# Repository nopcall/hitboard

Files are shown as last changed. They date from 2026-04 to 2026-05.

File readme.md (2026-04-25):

### HITBOARD 开源项目

Hitboard 是一个开源 Hitbox 项目，包含 Zero、Air 等不用型号以适应不同用户、不同场景的需求。它诞生于一个简单的需求：为何不能有一台既拥有键盘的紧凑布局，又具备 Hitbox 专业输入体验的设备？

本项目不仅提供可生产的文件，更完整记录了从 设计思路、CAD布局、PCB工业化 到 固件配置 的全流程。你可以直接使用，也可以将其作为起点，打造属于你自己的终极武器。

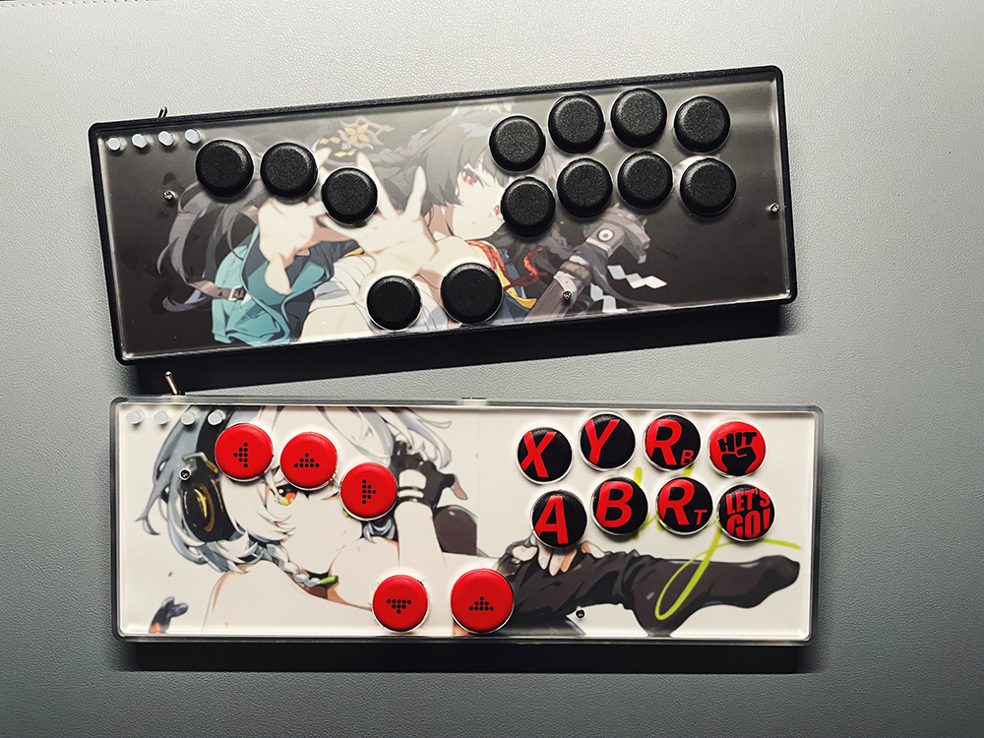
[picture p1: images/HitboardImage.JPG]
Hitboard成品图


#### 🎬 项目视频实录

本项目的完整诞生过程，已通过系列视频详细记录。如果你对背后的思考、踩坑的经历和具体的制作步骤感兴趣，强烈建议观看：

【【街霸6】180元手搓 Hitbox | 附材料清单设计源文件】 https://www.bilibili.com/video/BV1n8UQBeEs3/?share_source=copy_web&vd_source=521fa607e5f082de7ab25fcafb9cb9a2

【手搓Hitbox 第二弹：全程组装实录】 https://www.bilibili.com/video/BV15iUfBCE8V/?share_source=copy_web&vd_source=521fa607e5f082de7ab25fcafb9cb9a2

【手搓Hitbox 第三弹：生成CAD文件】 https://www.bilibili.com/video/BV1XumPBUEJE/?share_source=copy_web&vd_source=521fa607e5f082de7ab25fcafb9cb9a2

#### ✨ 型号说明
Hitboard Zero

从零开始的起点，为渴望亲手定义操控的创造者而生。纯亚克力多层结构，只需简单修改CAD文件即可调整布局，一切由你决定。这里仅提一套参考布局、PCB 源文件作为灵感，而非定死的答案。288×96mm键盘尺寸无缝融入桌面，双面壁纸让美学随你变换。它是你打造专属控制器的空白画布，也是通往深度定制的第一级台阶。

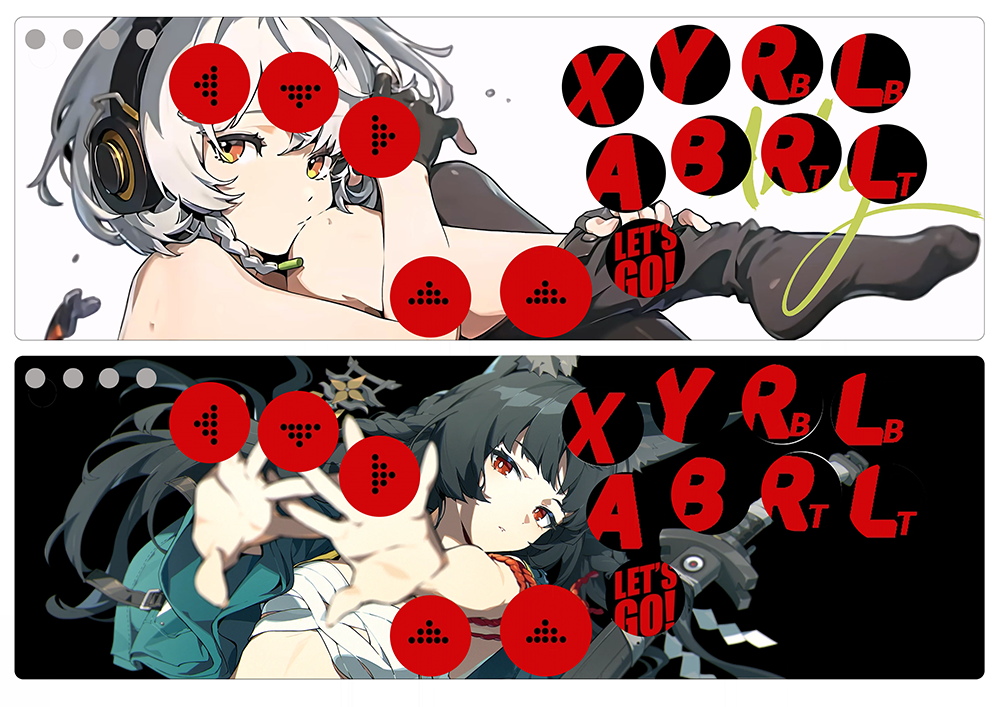
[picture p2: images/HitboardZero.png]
Hitboard Zero


Hitboard Air

像拼四驱车一样拼 Hitbox。基于3D打印技术实现，256mm宽度适配家用打印机。保留Zero的全尺寸按键布局，并提供更灵动的“拨片”加键。所有电路部分均为卡扣结构，可以方便的拆卸转移。

//由于卡扣结构的设计极其复杂，牵一发动全身。此型号提供全套 3D 打印文件作为标准答案。

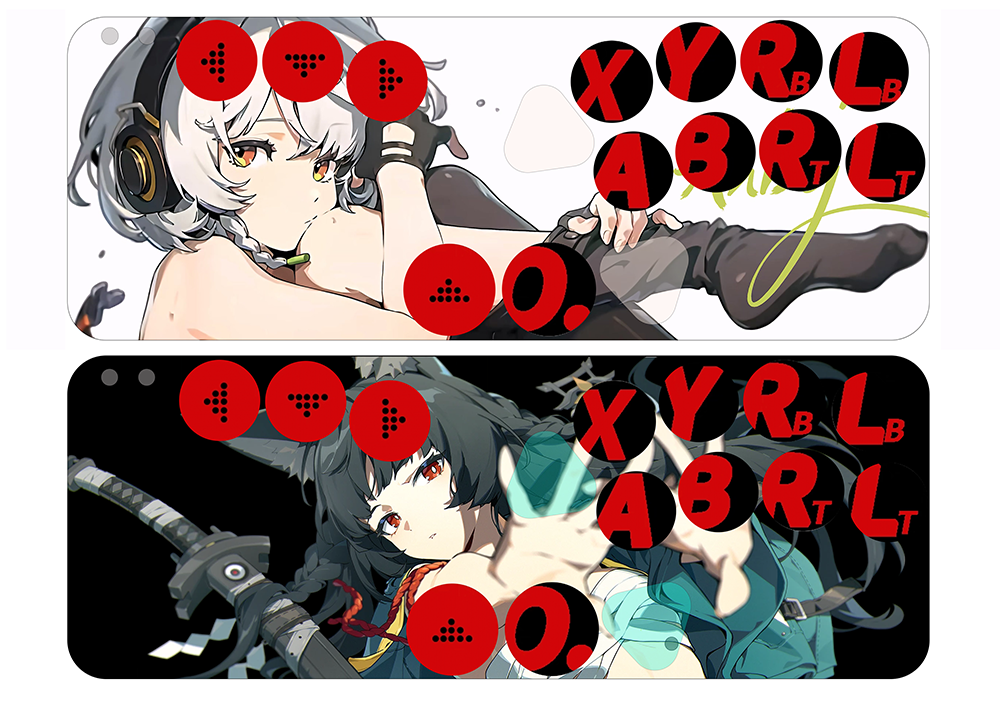
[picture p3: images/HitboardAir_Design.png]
Hitboard Air


Hitboard Classic

Hitboard Classic – 不只是摇杆：可翻转、可滑动、可换轴、可配重、可塞主板的开源格斗外设平台。

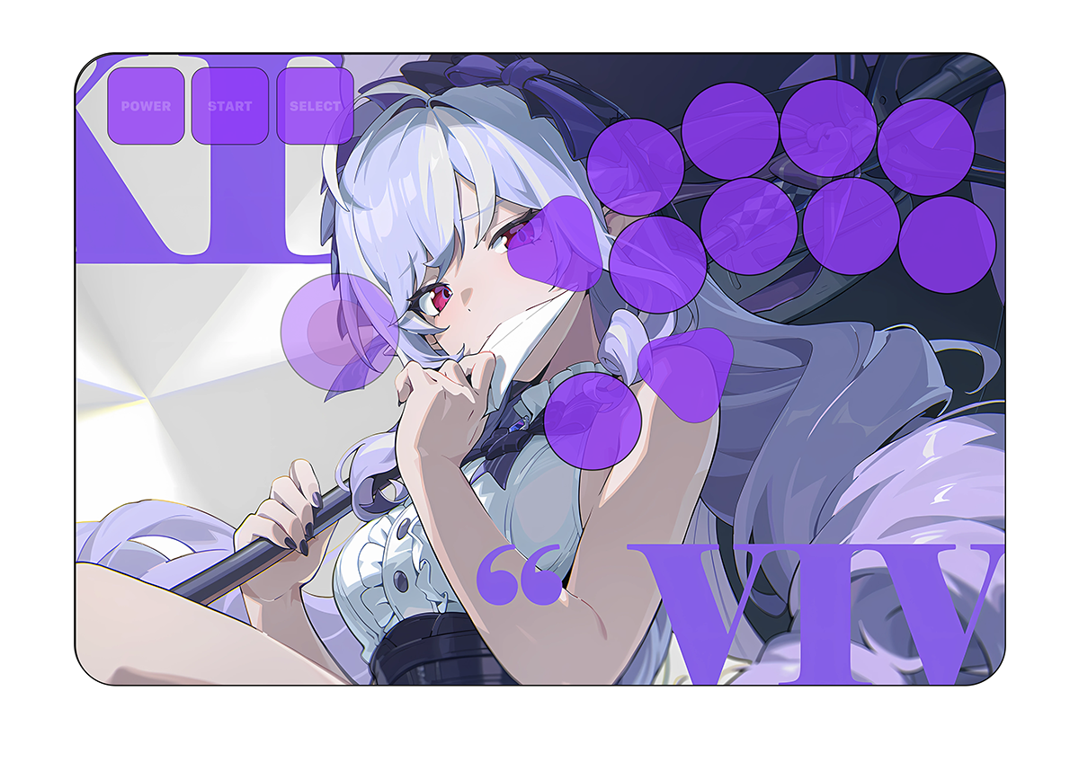
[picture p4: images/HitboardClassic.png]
Hitboard Classic


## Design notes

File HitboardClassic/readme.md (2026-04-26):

Hitboard Classic

Hitboard Classic – 不只是摇杆：可翻转、可滑动、可换轴、可配重、可塞主板的开源格斗外设平台。

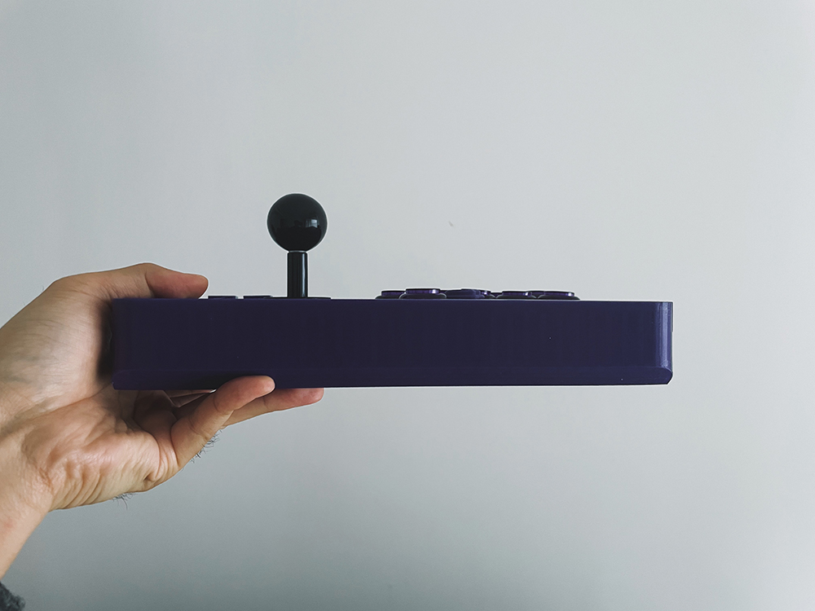
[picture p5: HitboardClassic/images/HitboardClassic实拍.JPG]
Hitboard Classic


Hitboard Classic —— 不只是摇杆

开场：科学街霸标准。
过去一段时间，我们一直在探索一个问题——好的格斗游戏外设，应该是什么样的。

由此提炼出一套科学街霸外设的标准：
* 分离式布局，放松肩膀。
* 左右对称 + 合理按键布局，减少手指疲劳。
* 功能键触手可及，提高训练场效率。
* 拨片加键键帽，跟拳脚键区分度高，不误触。
* 23-26mm 黄金尺寸，平衡触感与按键间距。
* 面板使用非金属、非玻璃材质，防止手感冰凉。

依据这些标准，我们做了 Hitboard Air。
但格斗外设，从来不该只有 Hitbox 这一种答案。

#### Hitboard vs 街机摇杆
Hitbox 把方向拆成四个独立开关——大脑先解构，手指再敲击。一步错，步步错。

街机摇杆不同。手掌、手腕、小臂协同发力——转圈、半圆，手腕一抖就出来。
长盘更稳，压力分散。这就是摇杆的哲学：不是更快，是更稳；不是拆解，是本能。

那既然摇杆这么科学，为什么被 Hitbox 抢尽风头，甚至举步维艰？
不是它不行了，是缺少创新的外设厂商，让摇杆跟不上时代。

通过本期视频——我们来让摇杆，再次伟大。

####第一部分：传统摇杆的问题

布局问题：
33mm 按键间距，手指根本够不顺。
功能键又小又远，训练场里形同虚设。
左右手高低差——视觉上对齐了，用起来却一高一低。
结果：手掌频繁抬起、移动，多出废操作。手被架空。
需要给设备增加配重来减少晃动。

摇杆问题：
圆档丝滑但蹲防不准，方档准但搓招卡。
八角档两边不讨好。厂商图省事，丢给你一个“能用就行”。

按键问题：
街机按键手感特殊，键盘玩家上来就劝退。
想换自己喜欢的 MX 轴或矮轴？没门——轴座又贵又难改。

外观问题：
又大又重，2公斤起步，放桌上占半张桌，放腿上压得慌。
想自己动手改？纯亚克力堆叠，山寨感拉满。

这样，新人还没入门，就被劝退。

####第二部分：Hitboard Classic 带来的新基准

基于此场景，我们推出 Hitboard Classic，用全新的基准来解决以上所有问题。

基准 1：科学布局
分离式布局
摇杆和按键拉开距离，肩膀自然放松。

对称布局
手掌对称，不是按键对称。
传统摇杆左右手高低差约35mm，Classic 把这个落差做到结构里，左右手掌始终在同一水平线。

优化的拳脚键布局
手掌自然放置就能覆盖所有按键。
现代模式也顺手。
自然放置的手掌，给设备提供了下压力，搓招不晃动。

功能键触手可及
功能键同 Air 一样放在左上角位置，左手无名指一勾就能按到，手不离杆。
三颗功能键，菜单、Func、重置，一个不落，提升训练场效率。

#### 基准 2：黄金摇杆标准

衡量摇杆好不好用，看两个指令：半圆、前前。

传统摇杆的问题：
圆档滑，但斜角没档位，蹲防拉不到位。
玩家被迫换方圆档/八角档。蹲防稳了，但因为相比圆档压缩了活动空间，摇杆被吃掉了行程。

行程变短带来两个问题：搓招指令不清晰；弹簧弹力变小，回中变慢，影响前前指令。
为了补漏洞，就得换大弹力弹簧，整个手感反人类——就像骑最高齿比的自行车上坡，腿脚根本不受控。

Classic 的方案：圆方档位。
优先保证圆的丝滑，四角做小切角。
不刻意拉斜方向时，它就是圆；拉斜方向时，蹲防清晰。

使用圆方档位，能让前后指令吃满行程。
这样，玩家可以用轻克力弹簧，通过行程带来的张力来回中。
相比通过大力弹簧硬拉，更符合直觉。
行程大，更不容易串招。

人类的手掌非常敏锐，虽然只差了几个毫米的行程，几个克的弹力曲线。
但，理顺了，自然了，就好上手。
新手几乎零学习成本，练一练就能追上自己 Hitbox 的操作水平。

#### 基准 3：快装轴座系统，实现按键自由

轴座自由
想用街机按键？可以。
想用 MX 轴？可以。
想用矮轴？也可以。

Classic 的快装轴座系统：买几个插簧，简单一装，就是机械轴轴座。
提供 MX 轴 / 矮轴 两种型号。
配合 24mm 盖板开孔，街机按键、矮轴、MX 轴，随便换。

根据每种轴体的行程，做了按键深度的适配，每种按键的按压都恰到好处。

键帽自由
提供 21mm 键帽（硬朗/圆润两种弧度），通过深度与边缘的配合，手感接近 23mm 键帽。
你也可以选择第三方的 21mm 键帽。
加键依然提供拨片形，薄、与拳脚键区分度高，不误触。
功能键支持全尺寸的键盘键帽。

### 基准 4：从极致的薄，到舒适的厚

Air 做到了 9.3mm，全球最薄。因为它定位在桌面环境，越薄体验越好。

Classic 更多的考虑了舒适度、健康度问题？
如何能远离屏幕，如何能更放松。
答案是，放在腿上使用。

为了放腿上，就需要一定的厚度，给手臂支撑，减轻手腕压力，
为了广泛兼容玩家喜欢的各类摇杆，就需要 36mm 以上的内部空间。
为了实现壁纸自由，需要再留出 4mm 的亚克力盖板厚度，
那么，40mm 就是满足舒适性、可玩性、摇杆类产品的，最薄极限。

这个厚度，在视觉上恰好不会显得厚重。
配合长宽比、一定的切角设计，使它看起来很小巧，愿意把玩。

与市面上的摇杆相比：
传统摇杆：35×21×5.5 cm，4042 cm³，2kg。
Hitboard Classic：25.6×17.4×4 cm，1781 cm³，650g。
体积少 56%，重量轻 60%。

得益于基准 1，在全面减负的情况下。
你得到了对手臂友好的、不压腿的、布局开阔无晃动的，街机摇杆。

广阔的内部空间，也带来了更多的电路选项。
可以继续使用Pico + GP2040，获得易用的手柄/键盘系统。
也可以加入电池、无线芯片，来 DIY 无线方案。
甚至可以50 块买个二手手柄，拆主板、电池，放进去秒变无线摇杆。

#### 总结：

Hitboard Classic 新基准

人体工学布局 —— 手掌对称，功能键触手可及

黄金摇杆标准 —— 圆方档位，丝滑且精准

快装轴座系统 —— 按键自由，免焊接零门槛

从极致的薄，到舒适的厚 —— 放腿无压，久玩不累

一套新基准，使摇杆变得科学、趁手、自由。
让摇杆，再次，伟大。

#### One more thing……一切皆可自定义

左右自定义
左撇子？右手方向、左手拳脚？
Classic 外壳左右对称，盖板上下对称。
翻转一下，镜像布局。
从形态到习惯，全部自定义。

形态自定义
不知道自己适合摇杆、Hitbox 还是 Mixbox？
Classic 全模块化设计。
拆掉摇杆，装上四个方向键 = Hitbox。
换上 WASD 盖板 = Mixbox。

配件自定义：
内部多个轨道，提供束线器、磁吸模块、电池仓、马达仓。按需 DIY。

Hitboard Classic 是什么？
不只是街机摇杆，而是一个格斗外设 DIY 平台。

如何开始？
Hitboard Creator for Classic，硬件自由，软件也自由。
一如既往简单强大。
一如既往，GitHub 搜索 Hitboard，打开网页工具，马上开始设计。

Hitboard
Find your fight.

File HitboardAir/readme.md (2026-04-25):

### Hitboard Air - 组装指南

### 准备工作：采购元器件

1. 下载网页工具：00_设计你的 Hitboard Air.html

2. 用浏览器打开该网页，设计你的 Hitboard。设计完成后，点击页面中的「导出产品配置」按钮，导出你的配置图片。

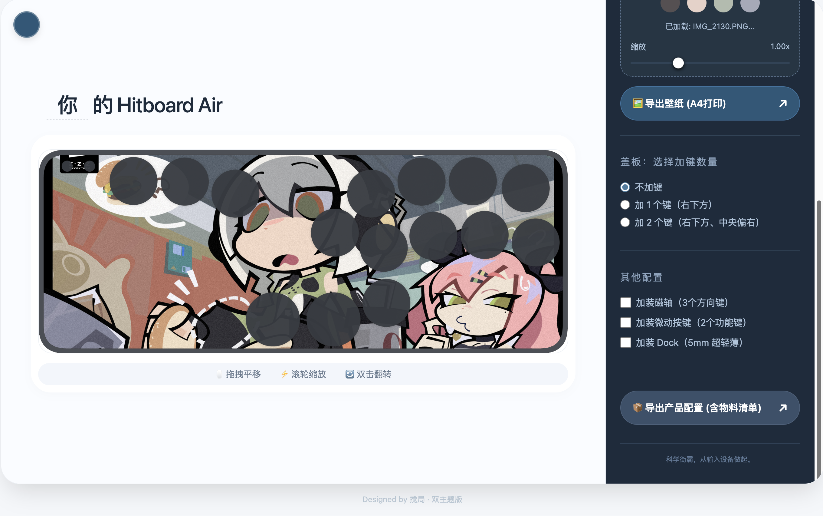
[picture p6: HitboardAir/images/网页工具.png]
HitboardAir 全部打印件


3. 根据配置图片中的物料清单，采购元器件、3D 打印套件。

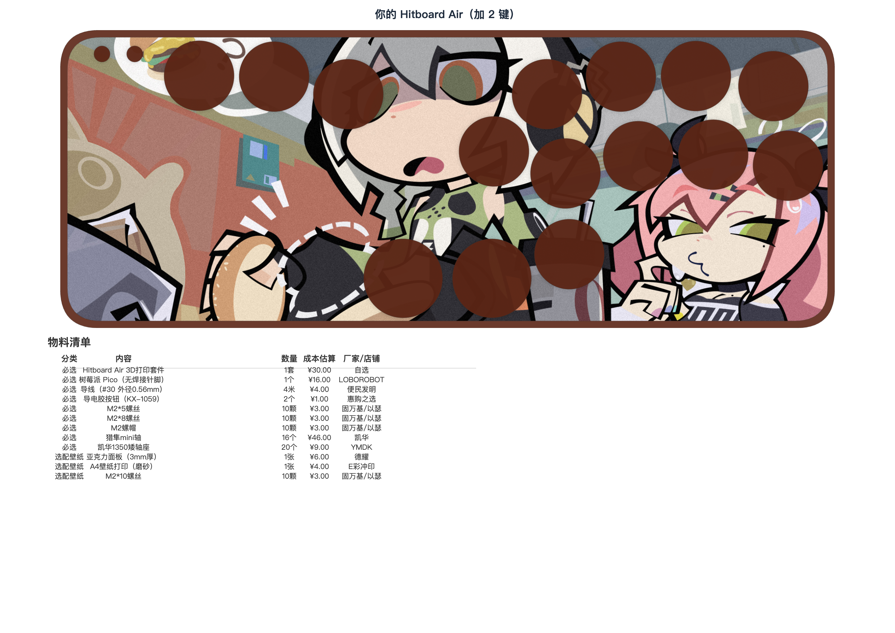
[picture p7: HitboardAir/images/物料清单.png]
HitboardAir 全部打印件


**3D 打印文件怎么选**

02_3D_Files 目录，包含两套 3D 打印文件，分别是：

「Hitboard Air - 圆润版」

「Hitboard Air - 硬朗版」

//两个版本只有外壳、按键的弧度有区别，内部零件通用。根据你喜欢的风格二选一，或全都选，即可。

HitboardAir 全部打印件

### 组装过程

### 第一步：给 Pico 刷入 GP2040 固件

1. 按住 Pico 复位按钮的同时，通过 typec 数据线连接 Pico 到电脑。此时 Pico 将会以 U 盘的形式出现。
    
2. 将固件「GP2040-CE_0.7.12_Pico.uf2」文件，拖拽到 Pico U 盘。
    
3. 等待几秒钟，Pico 会被重新识别为手柄。可以在手柄测试网页 https://hardwaretester.com/gamepad 查看手柄状态，用导线短接 GND 和任意信号引脚查看是否工作。

### 第二步：飞线连接元器件

打开「Pico背面图片」，观察的引脚示意图，了解引脚的基本情况。

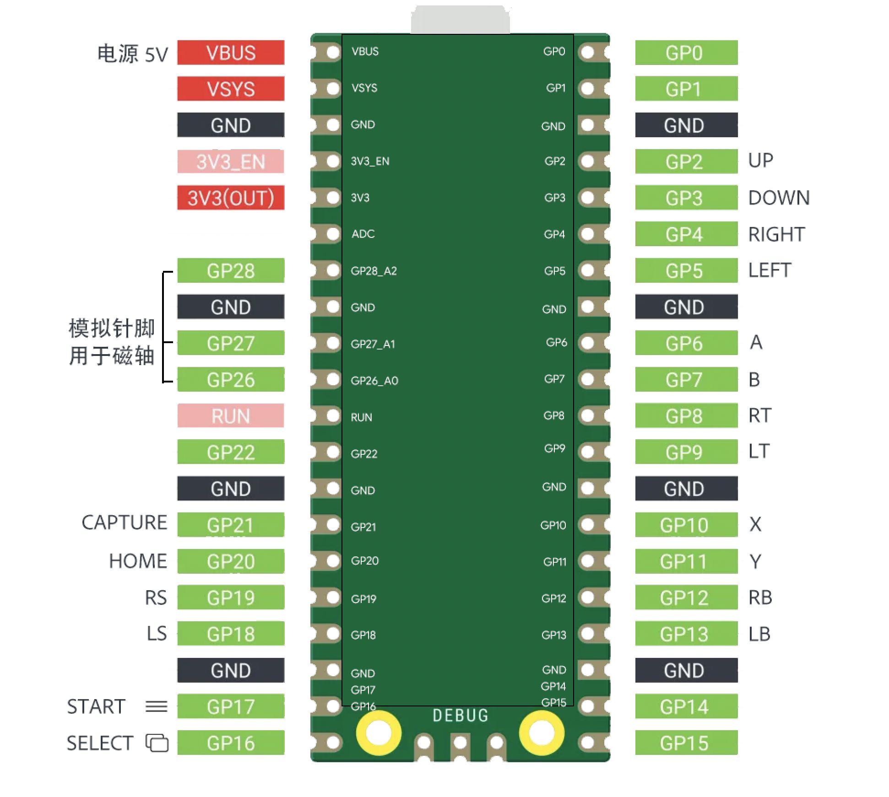
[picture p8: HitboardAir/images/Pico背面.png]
HitboardAir 全部打印件


1. 拿出「Hitboard Air 03 线路板」，板子上布满卡扣，依次将 Pico、轴座卡在对应的位置。

**注意！一定要是正面（有 USB 凸起）朝里，背面（绿色纯平面）朝向自己卡进去。**

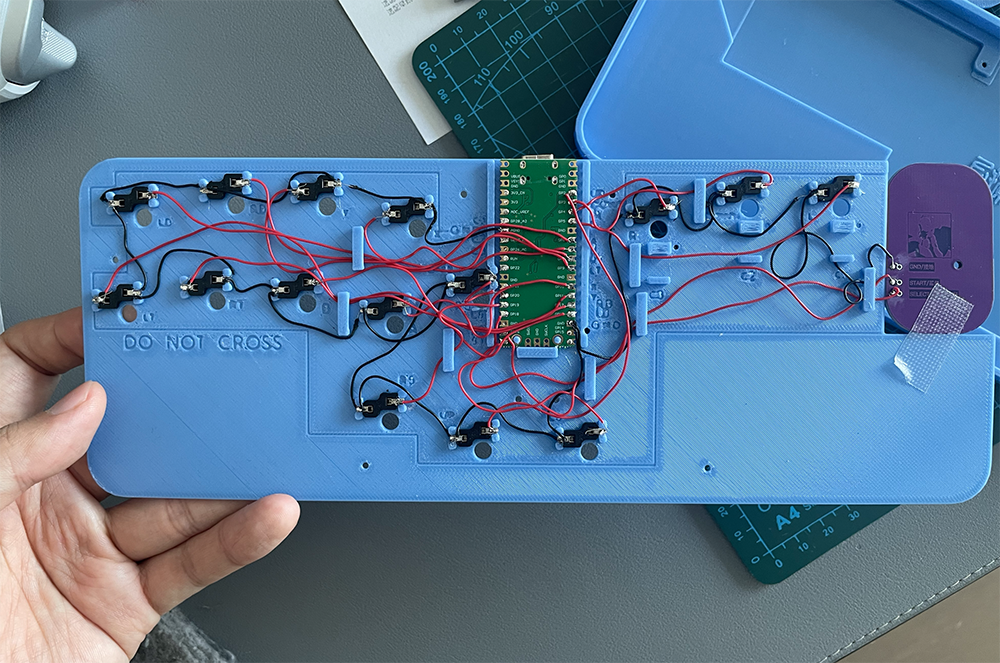
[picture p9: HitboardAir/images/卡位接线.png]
HitboardAir 全部打印件

    
2. 连接
    
    首先，留意线路板上的“警戒线”标注，警戒线内对应底壳空腔，表示线路可以被容纳。如果超出警戒线，则线路无法被容纳，组装时，无法放平整。

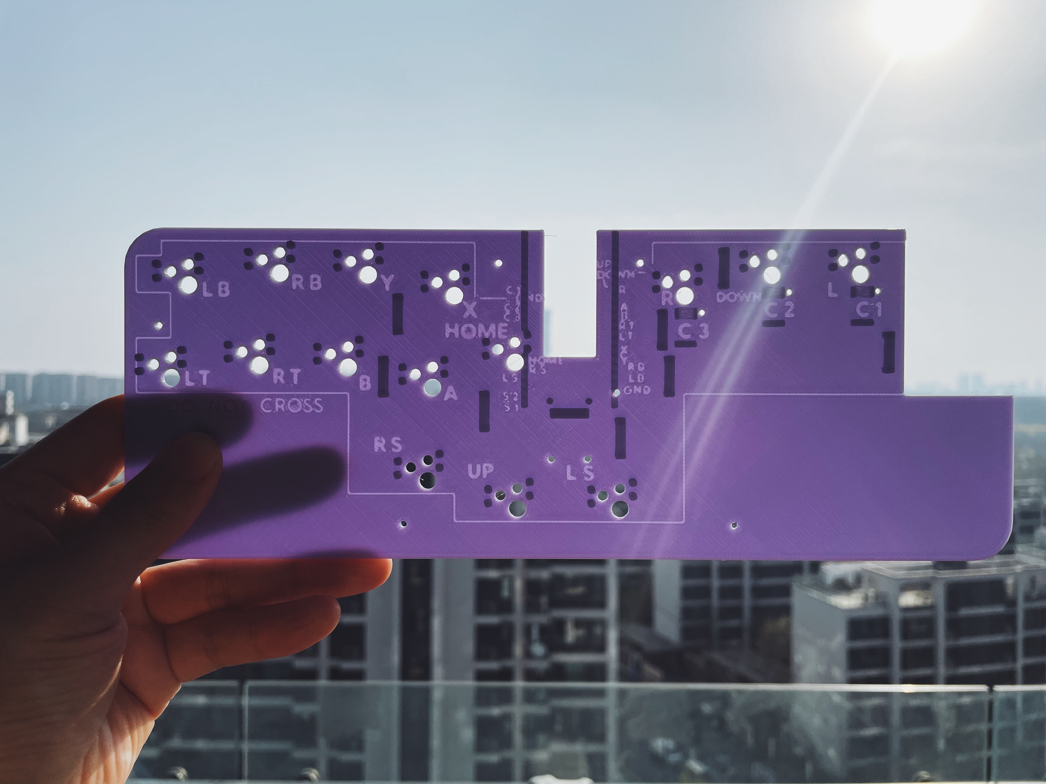
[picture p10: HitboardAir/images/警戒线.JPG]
HitboardAir 全部打印件


先来给每个按键接 GND。
    
    从 Pico 的任意 GND 方形焊盘，引出导线，将导线依次通过每一个轴座的任一引脚，焊接确保联通（或者缠绕连接）。这样就完成了按键的接地。
        
    将按键轴座另外一个引脚，接到对应的功能。比如方向键「Up」连接到 GP2 Up。
        
    把 4 个方向键、8 个功能键的轴座触点，通过导线，连到 Pico 对应的引脚。
        
    三个加键的轴座触点，连到 Pico 的 LS、RS、Home 引脚，后续需要在设置中，改为你需要的其他按键。

    Select、Start，默认使用导电胶+小电路板实现。把电路板上对应名字的焊盘，与 Pico 引脚相连即可。记得给小电路板连 GND。
        
    // 连接完成后，务必把 Pico 连接到电脑，用导线短接每个轴座的两个引脚。在手柄测试网页查看是否都能生效。
        
    // 如果不生效，检查是否虚焊，直到所有按键电路都正常工作。

### 第三步：组装所有板子

    将 03线路板、02定位板，依次放入04外壳。
    
    将轴体压入 02 定位板。//可以用手指挤压轴体左侧的外壳，让轴体不损耗卡扣
    
    放置导电胶按钮。
    
    准备盖板。通过 04 外壳的卡扣卡好即可。
    
    // 如果想要更牢固的固定盖板：
    
        先将 M2 螺丝帽，放入盖板背面的隐藏式螺帽仓。
    
        盖好盖板到外壳。
    
        从外壳背面，拧 6 颗 8mm M2 螺丝。
    
    从00按键中，取下按键，对应按键位置，一一装入。

### 软件设置

#### 按键配置

1. 按住 Start 按键的同时，通过 typec 连接电脑。
    
2. 访问 GP2040 Web 配置界面（通过 USB 连接后访问 192.168.7.1）
    
3. 点击「功能配置-GPIO 引脚配置」，将 LS、RS、Home 等按键，改为需要的按键。
    
    如果忘了哪个按键对应哪个。点击网页中的「引脚查看器」按钮，在 Hitboard 上按下需要配置的按键，网页会显示引脚编号（如果第一次检测无效就关闭弹窗再次点击）。
        
    在按键列表中找到对应的引脚，编辑按键即可。
        
#### 手柄性能设置：//必做

1. 点击「设置-游戏手柄设置」。
    
2. 将 SOCD 清理模式，改为「后输入优先」。
    
3. 将去抖延迟，改为 0 毫秒。

### 选配组件

#### Dock

先把本体滑入Dock上半。（滑入前，将 2 颗 M2 螺帽装入上半螺帽仓）

再把Dock下半卡入本体。

将 5mm M2 螺丝，分别从 Dock 左右两侧的螺丝孔拧入，即可完成固定。

锁线器：
    
    将 12 颗小磁铁，6 颗一组，压入锁线器的磁铁仓。
    
    将 6 颗小磁铁，3 颗一组，压入 Dock 的磁铁仓。
    
    将锁线器快装到 typec 数据线，即可使用磁吸锁线功能。

#### 盖板和壁纸

通过网页工具，制作下载壁纸图片。以 A4 尺寸打印，获得纸质壁纸。

对壁纸裁剪、打孔，取下 3D 打印盖板，替换为壁纸、亚克力盖板即可。

// 亚克力生产的 CAD 文件：其他/CAD 文件/Hitboard Air 亚克力.dwg

#### 磁轴

星磁mini轴的弹簧比较硬，我们先对弹簧手感进行调优。

剥开轴体，取下弹簧。将弹簧剪掉1/3。剪下的弹簧不要丢掉，以后可以用在功能键上。磁轴结构非常简洁，圆形磁铁对准圆形磁铁孔，装回即可。

这样轴体的手感就非常丝滑软弹了。如果想要磁轴、机械轴共存，剪掉磁轴右上方的塑料卡针即可。

搞定机械部分之后，我们开始处理电路。拿出选配零件中的霍尔传感器。窄面朝上，卡入线路板专用位置。传感器从右边起，分别是信号引脚、GND、3V3电压输入。每个传感器一一对应连接。

然后进入最后的软件校准环节。进入网页配置界面，
先进入LED配置，把默认占用的28引脚修改为其他引脚，释放这个模拟引脚。

然后进入插件设置，确保其他设置没占用模拟引脚的情况下，进入霍尔设置。

设置直连，26、27、28。然后对每个引脚绑定手柄键值，然后校准。

这里可以设置一个比较短的触发行程，让方向键快于拳脚键。对搓招儿的时间窗口比较有利。

最后保存触发值，重启设备。你的 Hitboard 就拥有了最顶级的性能。

### 关于手工缠线（免电烙铁）

手工缠线比电烙铁还要简单。要点是小孔缠线的技巧。
掐掉导线20cm左右的绝缘皮，对折导线头。

穿入对应的引脚焊盘孔，旋转Pico或导线，你就获得了由四股导线固定的引脚线
比单根导线有更大的强度和更大的接触面积。

绑定所有导线后，像装机走线那样集中安排走线就行了。

轴座端，缠两圈线，压扁轴座铁皮，一路引脚就固定好了。

轴座新增2个小过孔，方便GND裸导线从背面走线。

之后就是重复操作，不再赘述。

### 总结

我们从一堆散件开始，亲手完成了固件烧录、线路连接、整机组装和软件配置。最终得到的，不只是一台Hitboard——更是从零到一，把想法变成实物的能力。

科学街霸，从输入设备做起。Hitboard，让创造回归简单。

**【完】**

项目贡献者名单：@搅局无敌 @JennyPeng @匈牙利山猫 @Rev01ution

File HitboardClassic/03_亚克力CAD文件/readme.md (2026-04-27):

Hitboard Classic 亚克力

#### 1. 开孔尺寸

亚克力
考虑到亚克力厂家的公差，新版亚克力的「文件开孔直径」为 24.2mm，实得开孔直径大约为 24.3+-1。

3D 打印
直径24.6mm 的 PETG 打印轴座，收缩率之后，直径约为 24.4mm。

这样二者就能紧密卡住。

#### 2. 盖板尺寸

同样，根据公差，亚克力文件中的盖板宽高、圆角弧度，也跟 3D 打印文件中的盖板尺寸不同。

直接用一样的尺寸，会由亚克力厂的公差x3D 打印收缩率，而装不进去。

请知。

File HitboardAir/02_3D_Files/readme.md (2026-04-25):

### Hitboard Air - 3D打印设置

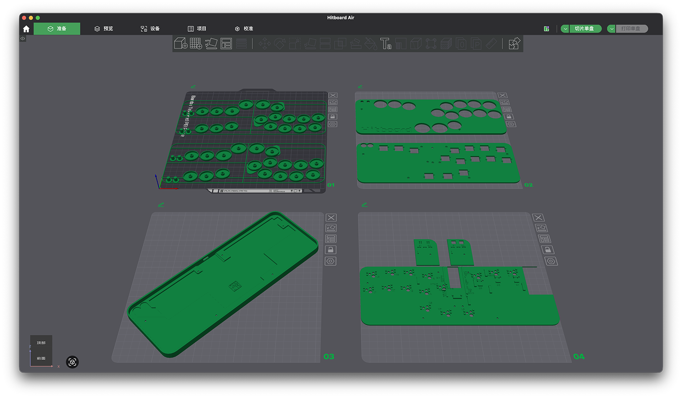
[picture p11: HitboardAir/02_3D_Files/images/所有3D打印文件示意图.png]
HitboardAir 全部打印件


#### 1. 文件说明

#### Hitboard Air 双版本 · 刚柔并济

**文件说明**

Hitboard Air 提供两种性格的版本——刚版与柔版。外壳、按键、Dock 三处的倒角设计，决定了设备整体的气质与手感。你可以根据自己的偏好，选择与你契合的那一款。

**刚 · 方正利落**
    
平整的极客体验。

    边缘干脆，线条直接。2.4mm 倒角仅做必要圆滑，保留直角带来的精准感。适合追求硬朗风格、喜欢清晰反馈的你。放在桌上，它是一块冷峻的金属感面板；握在手里，每一个棱角都在提醒你：这是一件趁手的工具。

**关键词：** 利落、精准、克制

**柔 · 圆润亲和**

温润的舒适体验。

    圆角过渡自然，握持更贴合手掌。每一个边缘都经过细致打磨，触感如鹅卵石般温润。适合长时间使用、偏爱柔和手感的你。它不会喧宾夺主，只是安静地承托你的每一次操作。

**关键词：** 圆润、舒适、包容

选择你的版本

刚与柔，没有好坏，只有不同。你的设备，该有你的性格。

##### 00_按键

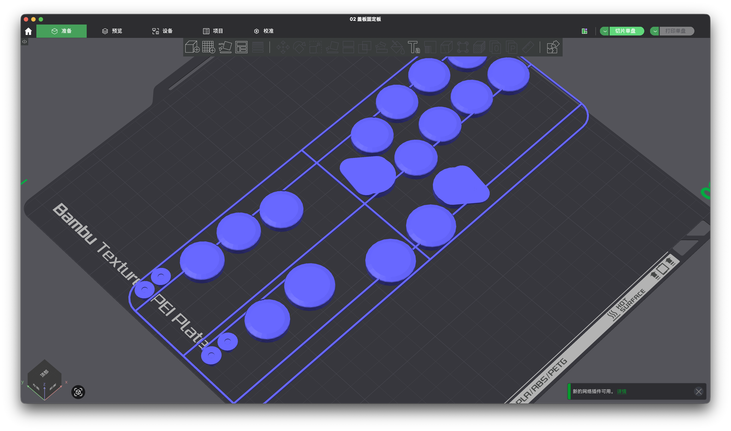
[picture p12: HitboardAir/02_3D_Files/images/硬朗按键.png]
HitboardAir 有刻键帽


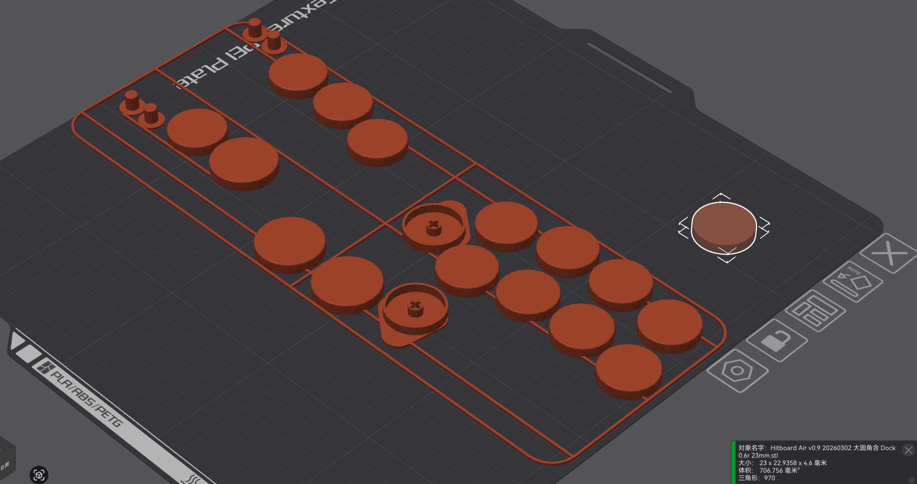
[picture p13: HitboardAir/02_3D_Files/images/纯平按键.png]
HitboardAir 有刻键帽


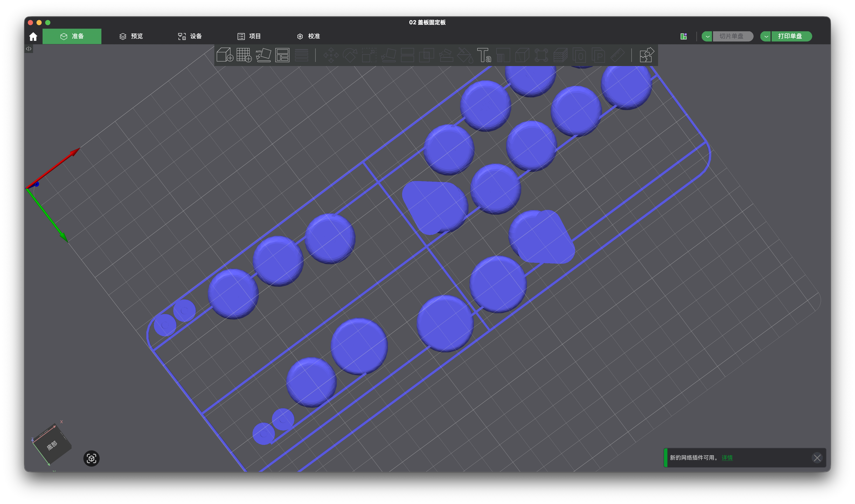
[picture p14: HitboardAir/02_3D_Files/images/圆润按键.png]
HitboardAir 有刻键帽


**键帽类型**

按键类型    命名    英文名    说明
2.5mm斜切    硬朗按键    Edge Key    线条硬朗，反馈清晰
0.6mm圆角    纯平按键    Flat Key    视觉纯平，手感顺滑不割手
3mm圆角    圆润按键    Round Key    明显圆角，手感柔和

**键帽触感**

按键根据键帽的朝向，有键帽朝上（正打）、键帽朝下（反打）两种方式。

正打能提供比较好的表面平整度，缺点是按键的确认感会不清晰。

反打按键的特点是，利用热床的颗粒，反打获得的表面随机颗粒效果，可以欺骗触觉（类似相机上的颗粒喷涂）。

// 注意：反打按键，需要在软件里把文件翻个朝向（也可以点击软件的「自动朝向」）。

**键帽刻字**

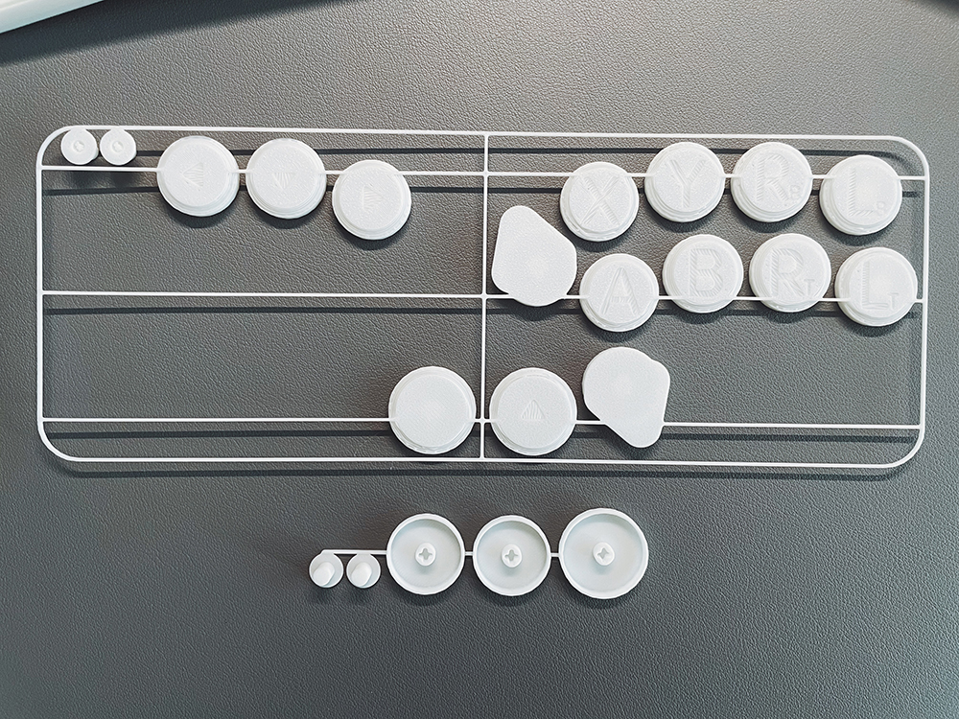
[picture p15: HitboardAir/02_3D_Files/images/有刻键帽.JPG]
HitboardAir 有刻键帽


有刻按键整体视觉上会好看一些，但会牺牲手感。推荐无刻。 （有刻在 More 文件夹中，有需要的自取）

##### ButtonsSystem

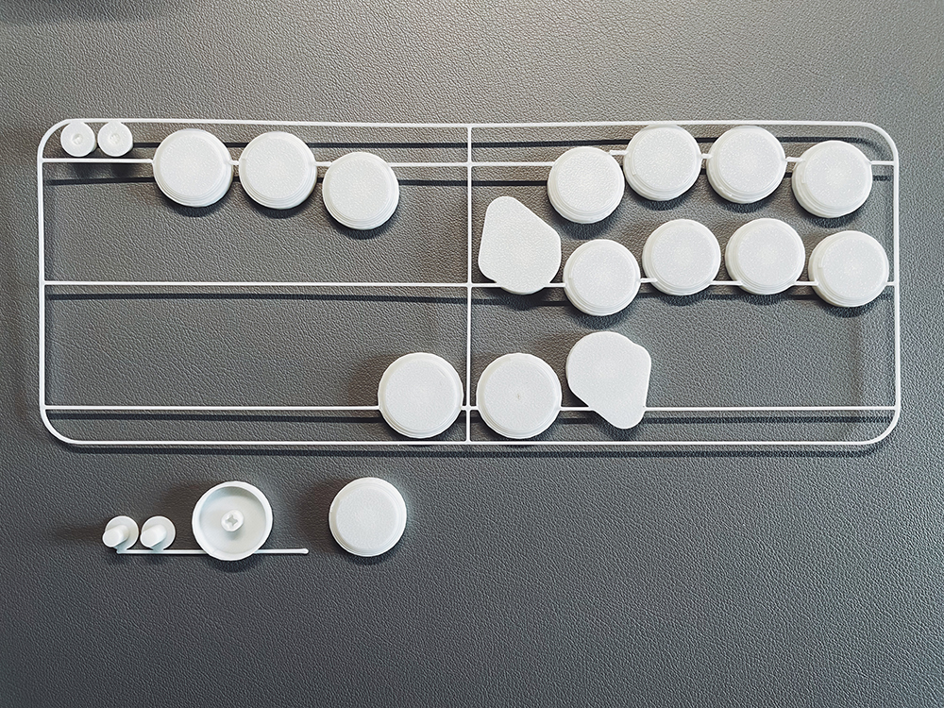
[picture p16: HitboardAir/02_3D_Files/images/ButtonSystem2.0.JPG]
HitboardAir 有刻键帽


按键通过中框串联，不会掉的到处都是。能一定程度防止运输过程丢按键。每套按键都提供了一组独立的备用按键，包含 2 个功能键、1 个 23mm 按键，1 个 26mm 按键。
        
中框已升级为 ButtonsSystem2.0，可以轻松的从框体取下键帽。喜欢拼高达，喜欢口水钳剪零件的同学可以打印这两套按键。

ButtonsSystem 已适配的按键组：
    
    00_Hitboard_Air_硬朗按键_全按键_无刻_带框_反打

    00_Hitboard_Air_圆润按键_全按键_无刻_带框_反打

##### More 文件夹

提供了更多的按键选项，进阶 3D 打印玩家可以多尝试不同的组合。

// 后续会持续研究 3D 打印按键，欢迎大家反馈这方面的需求。

#### For A1mini 180x180 文件夹

** 之后会适配 Amini 打印机的 180x180 尺寸，让每一个人都能享受到科技乐趣。 

** 01_盖板

用作产品上盖。
// 如果有自定义壁纸的需要。可以拿 CAD 文件，去花几块钱买一个 3mm 磨砂亚克力盖板。

盖板新增了 Logo
    
        “跟人约战街霸，对方没听过 Hitboard。你掏出设备，一个没有 Logo 的 3D 打印件——对方看了一眼，没说话。”

        “你知道他在想什么：山寨货。”

        “尴尬。”

        “Logo 不一定为了让别人认出来。有时候，是为了不让别人认错。”

** 02_定位板

// 定位板、轴座板，支持凯华矮轴：猎隼 mini、紫鸳、孤岛粉 mini、星磁 mini 等

用于支撑、固定机械轴。
    
安装轴体时，可以用手指按紧机械轴左侧的塑料臂，然后再往里按。这样能有效提升卡位结构的寿命。

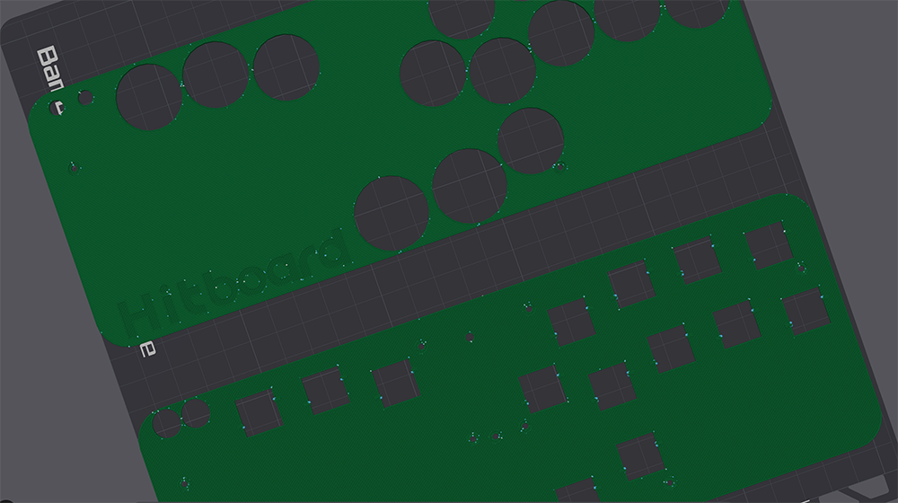
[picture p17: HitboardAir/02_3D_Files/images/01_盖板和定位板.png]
HitboardAir 按键


** 03_线路板
    
用于安装轴座、Pico 主板、飞线、功能键微动按钮。
    
线路板有凹印文字，标记了引脚。飞线时可参考标记接线。
    
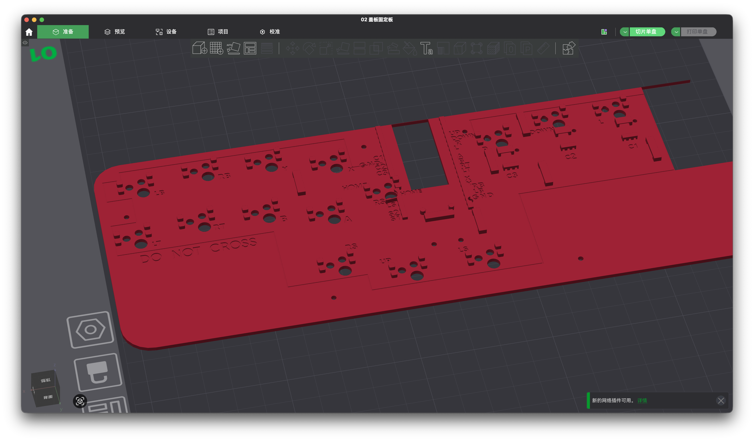
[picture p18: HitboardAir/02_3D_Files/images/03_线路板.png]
HitboardAir 线路板

    
「more」目录，提供了单独的「功能键小板」文件。方便单独补零件。

** 04_底壳
    
底壳提供 9.3mm（超薄）、9.7mm（中薄）两个文件。
    
这里优先推荐 9.3mm 外壳，因为 9mm 左右恰好能让键盘的厚度没有存在感，不硌手。9.7mm 的厚度，键盘底部边缘会有存在感，请知。

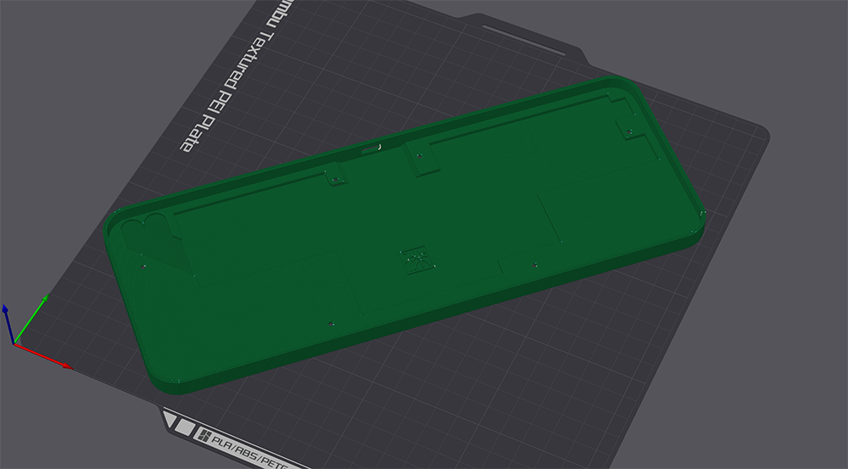
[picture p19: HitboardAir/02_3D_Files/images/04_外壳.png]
HitboardAir 按键


关于边框：默认提供 2.4mm 的边框，能让彩色外壳线条更美观。//more 文件夹有原 2mm 边框，有需的自取。两种边框外圈都是一样大（260x100）

#### 2. 打印设置

** 支撑设置

01、02、04 板子，按默认面打印。00按键、03板子，需要在打印软件里翻个面。// 点击拓竹的自动翻面就可以

用不用支撑差别不大，可以开启树状支撑保险一点。

// 经常为了赶时间开狂暴模式打印，狂暴模式下出品质量也可以，因为基本都是垂直件没有悬浮。

** 朝向设置

04 外壳，倾斜 45 度打印，能让打印机的纹路横竖走，而不是 45度倾斜走。这样纹路会更方正、更有稳定感。。

00、01、02、03，用默认的朝向打印，45 度纹路，视觉上减少存在感。

#### 3. 打印材料

Hitboard Air 是基于 PETG 材料设计，有足够的强度和耐久度，计划长时间使用的话推荐使用 PETG 作为打印材料。

// 鉴于很多人的 3D 打印机只能打 PLA，对 PLA 也做了打印测试：精度、强度都还不错。长时间使用耐久度待观察。

// 注意！PLA 高温下容易形变，打印完成后，务必等板子冷却后，再取。否则可能会让板子弯曲。

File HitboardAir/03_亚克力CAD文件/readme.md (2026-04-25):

### Hitboard Air - CAD 说明
文件中为 Hitbox 的盖板。提供了 A、B、C 三个型号：

    A 带有两个加键（右手大拇指右侧、A 与 X 的左侧）

    B 只带一个加键（右手大拇指右侧）

    C 不带加键

// 下单无需 CAD 程序，根据型号列表报给商家就可以。

// 定位板是按照 2 个加键设计的卡位凸起，如果选择了 B、C 盖板，把定位板上的凸起剪掉就可以。

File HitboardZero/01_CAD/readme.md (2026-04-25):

### Hitboard Zero CAD 使用说明

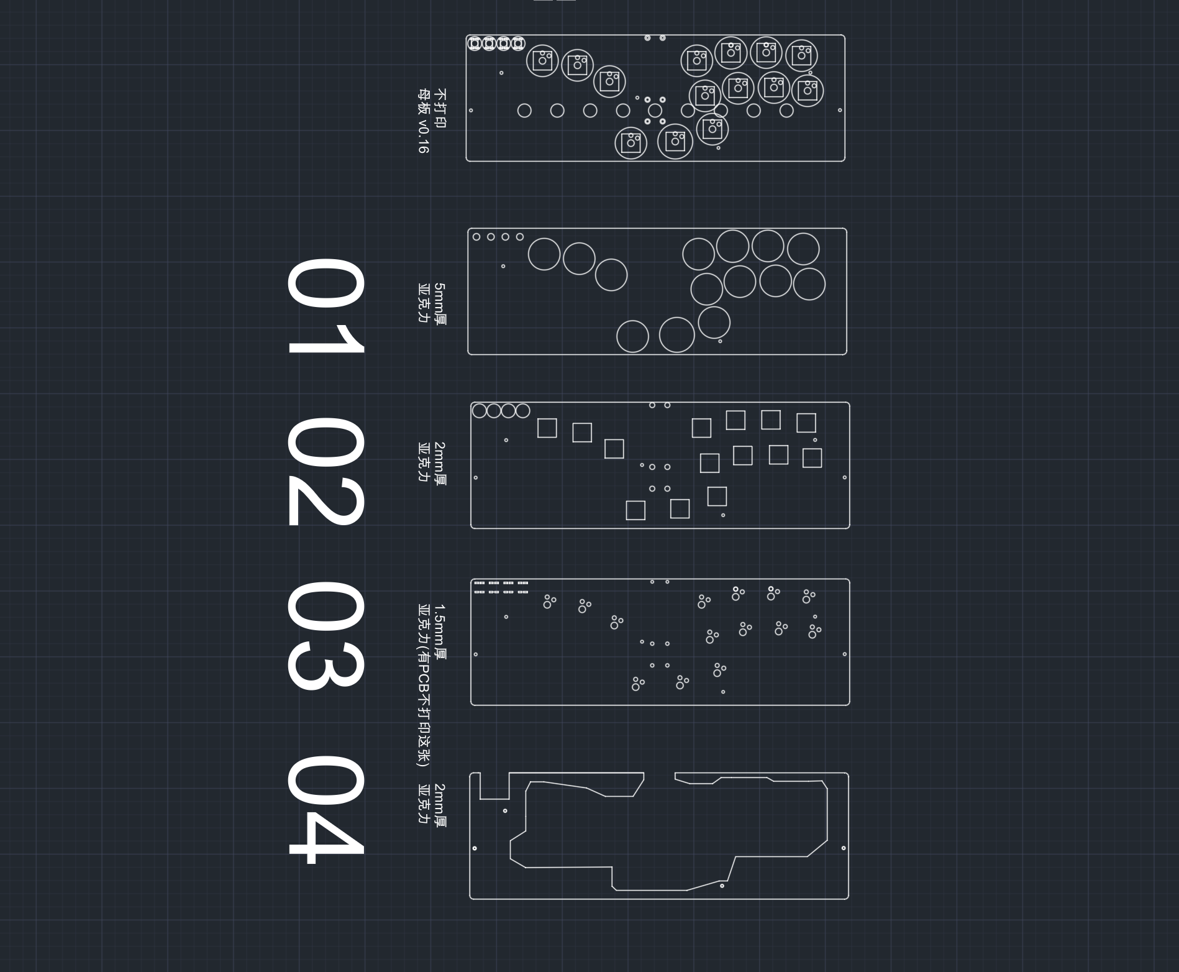
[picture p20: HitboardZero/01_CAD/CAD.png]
Hitboard成品图


#### 01 盖板

3-5mm 厚

放在顶层起到支撑手掌和展示壁纸的作用。一般采用透明亚克力或磨砂亚克力材质。

// 如果是亮色的壁纸，磨砂亚克力可以很好的柔光。如果是暗色的壁纸，透明亚克力可以让黑色更深沉。

#### 02 定位板

2mm 厚

14x14 的开孔，用于固定键盘轴体，并支撑敲击按键时的力。
// 中间有两组开孔，用户容纳螺丝的螺帽。

#### 03 轴座板

1.5mm 厚

用于支撑机械轴的轴座。将轴座插入每个按键的两小孔，并使用胶水固定。
// 中间两组螺丝孔，用于固定 pico。

#### 04 支撑板

2mm 厚

用于制造空腔，容纳轴座、pico、飞线。

// 顶部横梁默认是不断开的，提供更好的支撑性。如果是 typec 中央开孔，可以自行剪断。

#### 05 底部壁纸板

1mm 厚

用于支撑壁纸。//背面不放壁纸就不需要打印

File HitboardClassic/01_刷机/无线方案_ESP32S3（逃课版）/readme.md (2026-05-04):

# Hitbox 无线系统 - 三步搭建教程

准备工作：
- 两块 ESP32S3 芯片。
- 项目中的代码拷贝到本地。

### 第一步：烧录发射端、接收端程序。
先获取它们的 Mac 地址。
1.  用 Arduino IDE 新建一个项目。把获取 Mac 地址的代码粘贴进去。连接 ESP32，点击 IDE 的右方向按钮，上传程序。
#include <WiFi.h>

void setup() {
  Serial.begin(115200);
  // 等待串口就绪（尤其对于 ESP32-S3 原生 USB CDC）
  delay(2000);
  
  WiFi.mode(WIFI_STA);
  
  // 确保 WiFi 已启动
  delay(100);
  
  String mac = WiFi.macAddress();
  Serial.println("=== ESP32 MAC Address ===");
  Serial.println(mac);
  Serial.println("=========================");
}

void loop() {
  // 每隔 5 秒重复打印一次，防止错过
  static unsigned long lastPrint = 0;
  if (millis() - lastPrint > 5000) {
    lastPrint = millis();
    Serial.println(WiFi.macAddress());
  }
}

点击 IDE 的串口查看按钮，看到 Mac 地址，并记录到本地备份。
把发射端的 Mac，填到接收端。
把接收端的 Mac，填到发射端。

2. 连接每块 ESP32 到电脑，分别烧录进去填完 Mac 地址的，发射端代码，和接收端代码。
这样你就得到了能读取引脚信号，并且有线或无线发送串口信息的设备。

### 第二步：把发射端装到设备里，并按引脚图接线。

### 第三步：运行 PC 端 Python 程序

0. 问 AI 的方式，在你的电脑上安装 Python 环境。

1. 在终端通过 python 命令安装需要的库：
pip install pyserial flask vgamepad pynput

2. 运行 python 程序：
把发射端或者接收端连接到电脑，终端运行：
python pc_HitboardJoyCon.py

程序会自动扫描端口，并模拟手柄、启动网页配置服务。

如果需要改键，浏览器访问 `http://localhost:5000`：
   - 按下 Hitbox 按键，网页上对应的 Btn 会高亮。
   - 为每个物理按键配置 1~2 个手柄输出（例如把 Btn0 映射到 Xbox 的 A 键）。
   - 切换 Xbox / Switch / PS5 显示模式（仅改变网页上的按键名称）。

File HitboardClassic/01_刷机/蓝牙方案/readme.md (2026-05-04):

ESP32-BLE-Gamepad (核心库)

作用：让你的ESP32能被电脑识别为一个蓝牙游戏手柄，是处理按键、摇杆等所有输入功能的核心。

安装：在Arduino IDE中，打开 工具 > 管理库，搜索 ESP32-BLE-Gamepad 并安装。

NimBLE-Arduino (依赖库)

作用：它是一个更现代、更轻量的蓝牙栈，新版本的 ESP32-BLE-Gamepad 库（尤其是3.0以上版本）需要它才能正常工作。

安装：在Arduino IDE的库管理器中，搜索 NimBLE-Arduino 并安装。

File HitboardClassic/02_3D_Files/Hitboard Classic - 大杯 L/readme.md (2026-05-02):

Hitboard Classic 尺寸选择

标准版（中杯）：256x174mm，摇杆边距74mm。
//特点是小巧，让人愿意拿起来玩。内部放钢珠可以配重到2.5KG。

加大版（大杯）：290x180mm，摇杆边距90mm。
//宽度更大，可配重到5KG。
//更加的分离式布局，比标准版多 30mm 左右间距，久玩不累。

全新设计的新大杯，好用、好看。

两个型号，都支持A1mini打印机。

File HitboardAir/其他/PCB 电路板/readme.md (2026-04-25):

### Hitboard Air - PCB（电路板） 说明
Hitboard Air 的设计初衷是模块化组装，飞线连接。不需要整块的电路板。

加入小电路板的目的是，让小朋友或者萌新能接触到最简单的PCB电路，对电子工程产生一些模糊的概念。

// 3D 打印文件，03 线路板中附带的「功能键零件」不论是手搓导电电路，还是使用微动按键，都能实现很好的功能键体验。

// 可以不使用此 PCB。

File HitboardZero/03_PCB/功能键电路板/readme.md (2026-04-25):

### Hitboard Zero PCB（电路板） 说明
使用亚克力和飞线作为电路

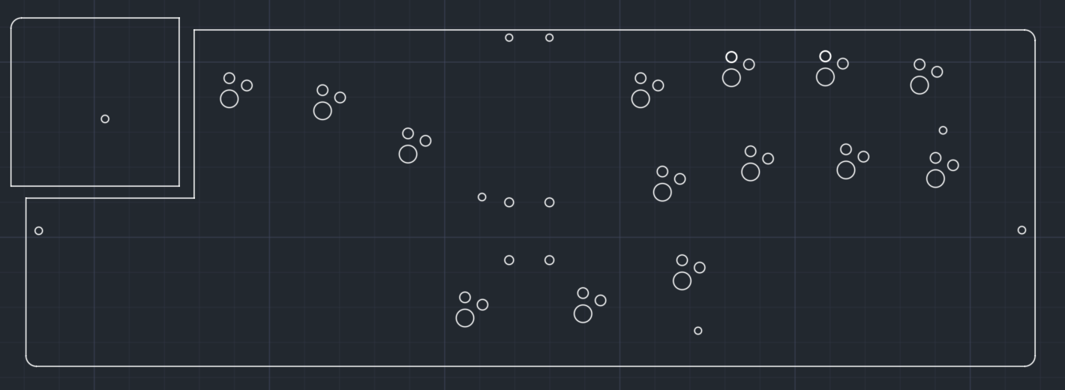
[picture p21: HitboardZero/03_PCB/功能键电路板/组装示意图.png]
Hitboard成品图


「03 轴座板」左上角设计了一个 48x48 的缺角。只需要使用嘉立创免费券，打印一个 48x48 的功能键电路板，就可以替代掉之前铜箔胶带贴电路的操作，更简单、更稳定。

// 推荐最开始使用飞线方案。因为把 Pico 焊接到 PCB 之后，几乎无法无伤拆解。等验证找到适合自己的布局之后，再考虑 PCB。

// PCB 相比飞线，所需要的焊点数量是一样的，并不会省时间。PCB 制造耗能、耗材料，不环保，不建议使用大块的 PCB。

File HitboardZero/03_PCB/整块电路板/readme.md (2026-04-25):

### Hitboard Zero PCB（电路板） 说明 

鉴于市面上的 GH60 壳子五花八门，不规格。忙完这一阵子，会集中出一个高兼容性的 PCB。

敬请期待。

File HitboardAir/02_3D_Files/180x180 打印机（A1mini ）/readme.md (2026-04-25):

### Hitboard Air - For A1mini

20260319
-大幅增强了 A1mini 版本的结构强度。

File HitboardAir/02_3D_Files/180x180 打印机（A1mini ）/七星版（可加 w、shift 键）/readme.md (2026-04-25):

### Hitboard Air - For A1mini

00 按键、04 外壳，分为硬朗版和圆润版，根据自己的喜好二选一，或全都选。

01 盖板、02 定位板、03 线路板，是硬朗、圆润通用的，逐个打印。

// 盖板文件中，有全套封帽（包括摇杆封帽），根据自己需求自定义。
// 需要更多配件，去：HitboardAir/More - 更多配件/

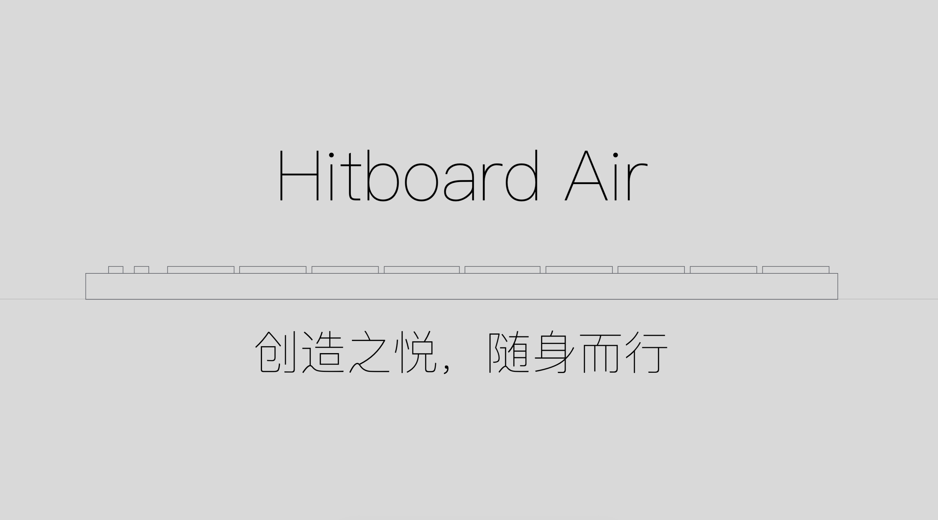
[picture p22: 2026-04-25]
HitboardAir/images/封面.png

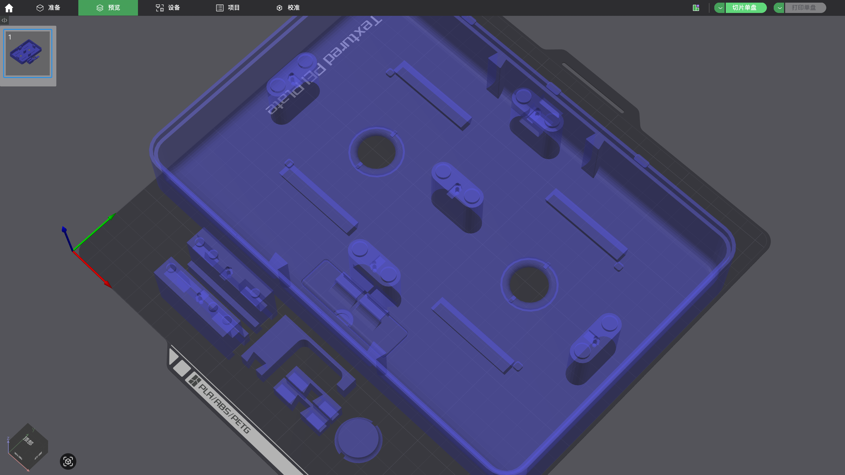
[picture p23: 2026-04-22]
HitboardClassic/images/外壳套件.png

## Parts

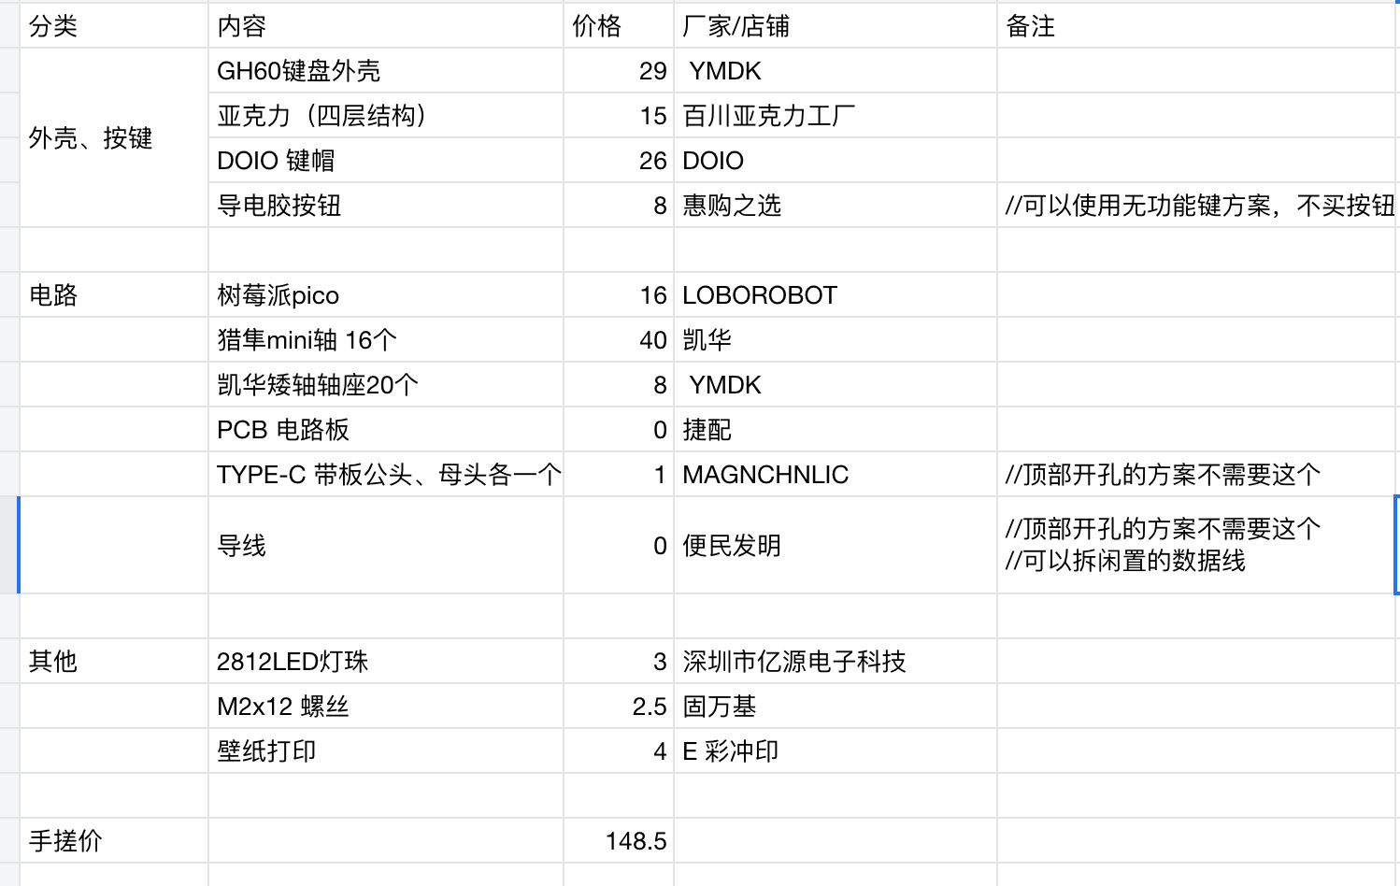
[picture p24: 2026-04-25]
HitboardZero/HitboardZero 物料清单.png

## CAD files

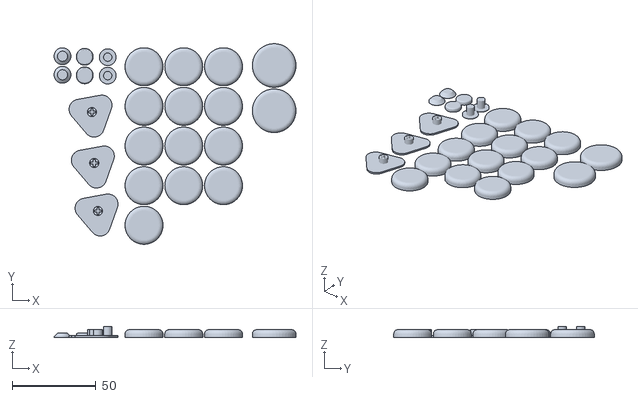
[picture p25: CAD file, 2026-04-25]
HitboardAir/02_3D_Files/180x180 打印机（A1mini ）/七星版（可加 w、shift 键）/圆润/00_按键_圆润整套正打.stl
144.2 x 119.5 x 6.40

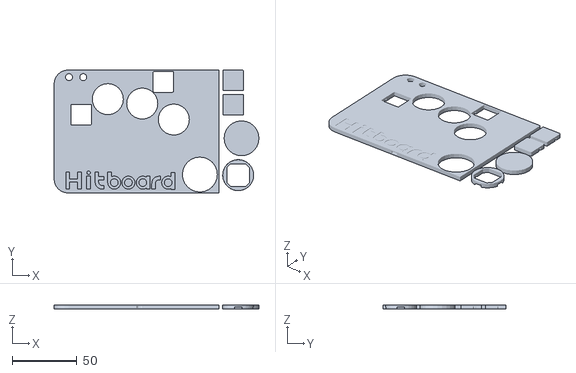
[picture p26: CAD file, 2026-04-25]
HitboardAir/02_3D_Files/180x180 打印机（A1mini ）/七星版（可加 w、shift 键）/硬朗/01_盖板_左半.stl
158.4 x 95.2 x 3.40

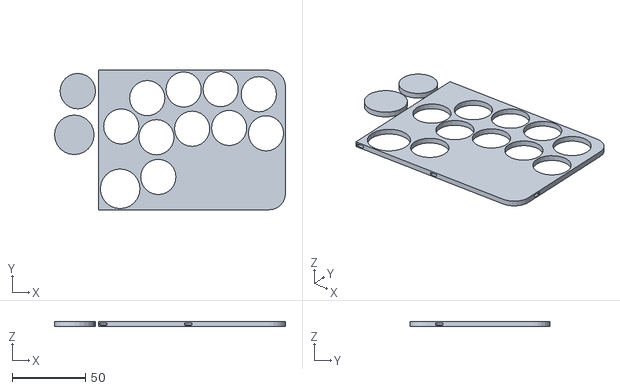
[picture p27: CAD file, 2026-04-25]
HitboardAir/02_3D_Files/180x180 打印机（A1mini ）/对称版/圆润/01_盖板_右半.stl
157.5 x 95.2 x 3.40

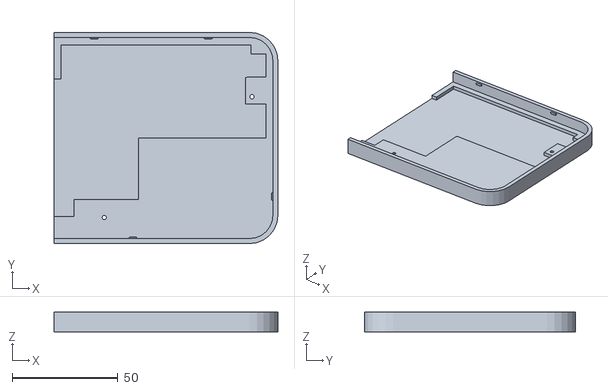
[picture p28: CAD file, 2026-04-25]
HitboardAir/02_3D_Files/180x180 打印机（A1mini ）/对称版/硬朗/04_外壳_硬朗_右半.stl
106.0 x 100.0 x 9.30

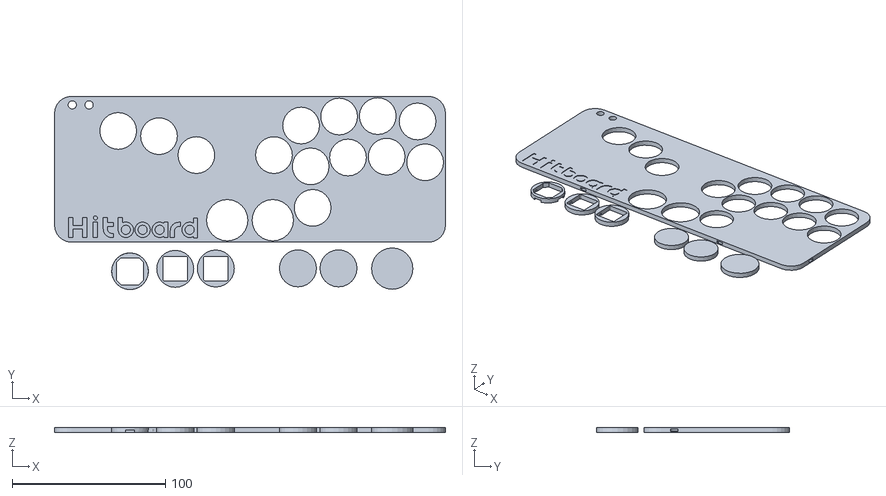
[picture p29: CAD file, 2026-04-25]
HitboardAir/02_3D_Files/Hitboard Air - 七星版（拳皇:绝区零:音游）/More/01 盖板 no w shift.stl
255.2 x 126.2 x 3.40

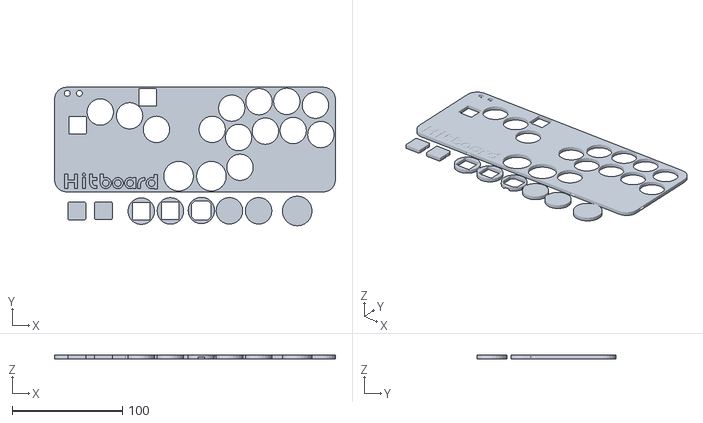
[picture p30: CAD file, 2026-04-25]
HitboardAir/02_3D_Files/Hitboard Air - 七星版（拳皇:绝区零:音游）/硬朗线条/01 盖板 w&shift.stl
255.2 x 125.9 x 3.40

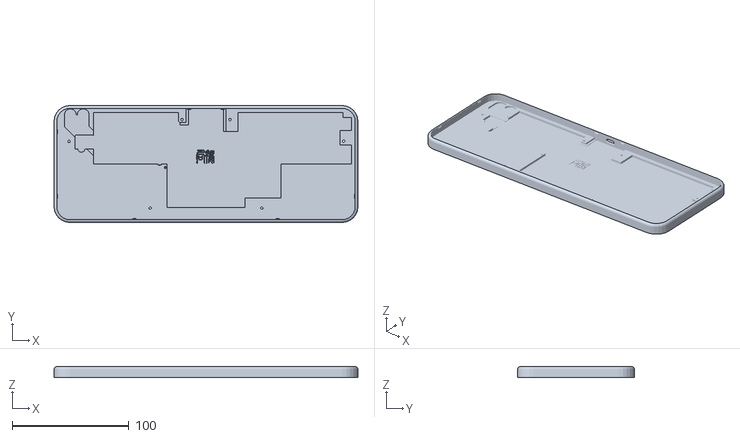
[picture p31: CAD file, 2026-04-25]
HitboardAir/02_3D_Files/Hitboard Air - 对称版（街霸特调）/圆润线条/04_外壳.stl
260.0 x 100.0 x 9.30

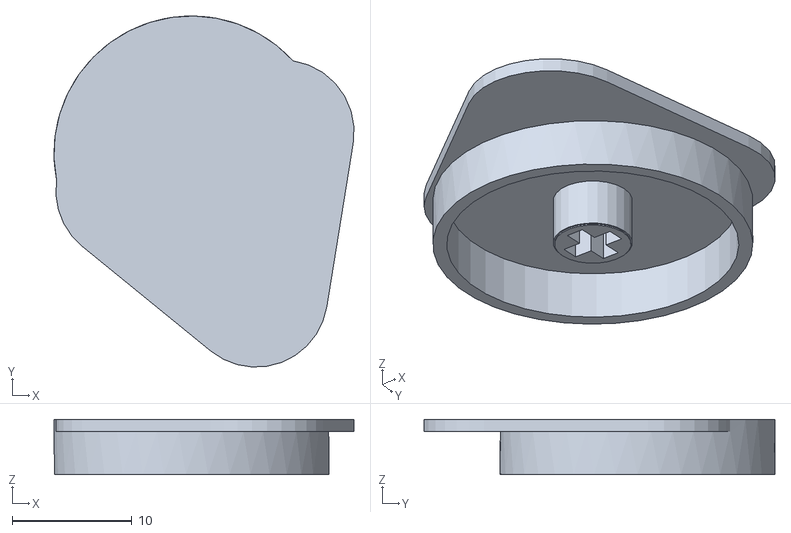
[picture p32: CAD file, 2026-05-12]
HitboardAir/02_3D_Files/More - 更多配件 /00_按键配件/圆形按键带拨片.stl
25.1 x 29.4 x 4.60

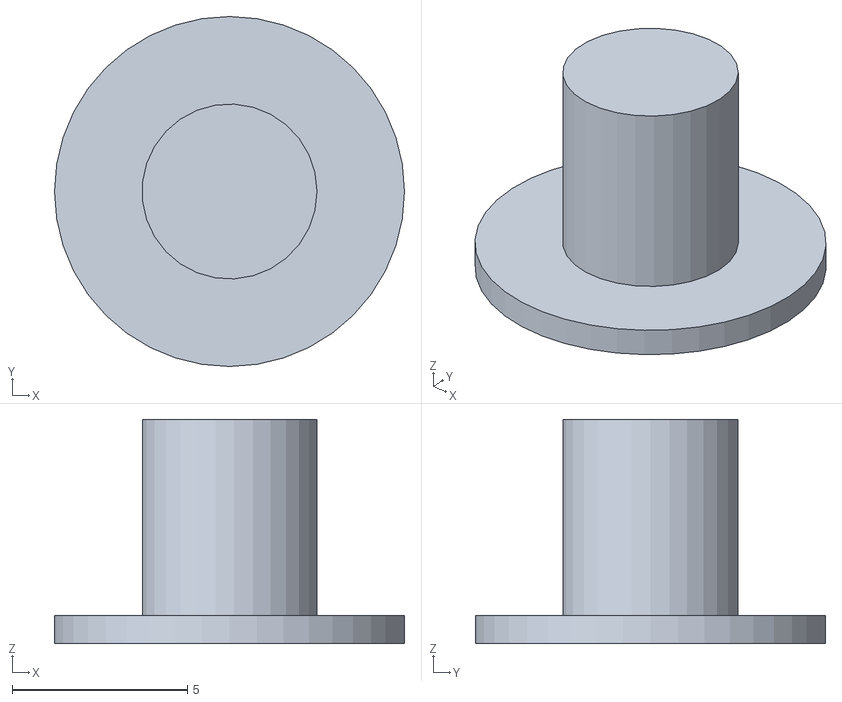
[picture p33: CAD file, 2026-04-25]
HitboardAir/02_3D_Files/More - 更多配件 /00_按键配件/配件_功能键/功能键单个.stl
10.00 x 10.0 x 6.40

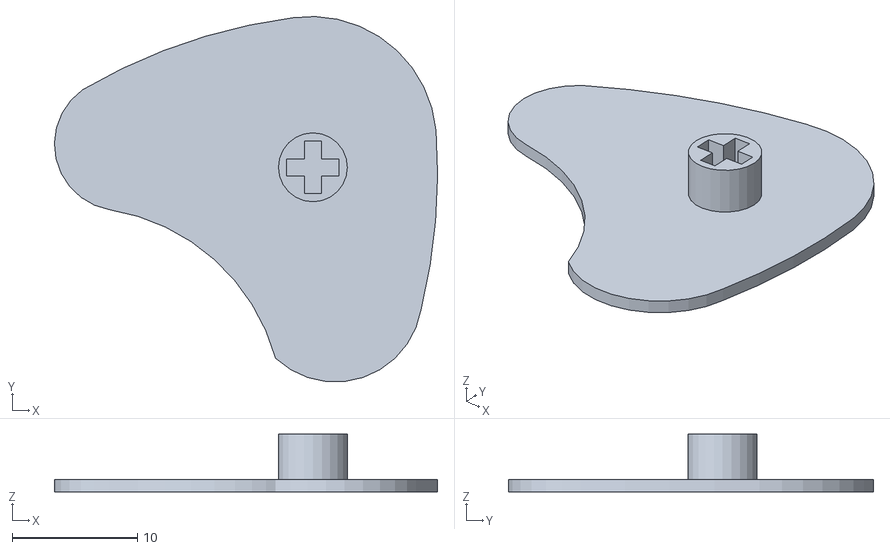
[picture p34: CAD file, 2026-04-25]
HitboardAir/02_3D_Files/More - 更多配件 /00_按键配件/配件_加键/软糖.stl
30.6 x 29.1 x 4.60

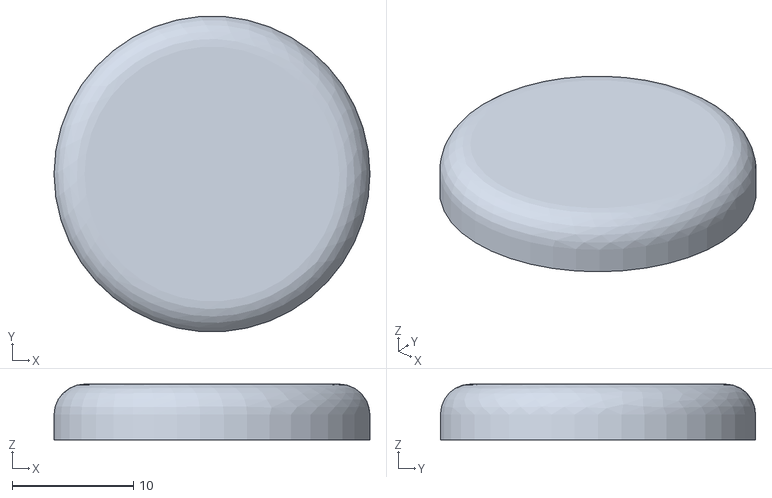
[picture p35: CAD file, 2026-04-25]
HitboardAir/02_3D_Files/More - 更多配件 /00_按键配件/配件_标准按键/00_圆润按键 （单个）/完美圆润 26mm.stl
26.0 x 26.0 x 4.60

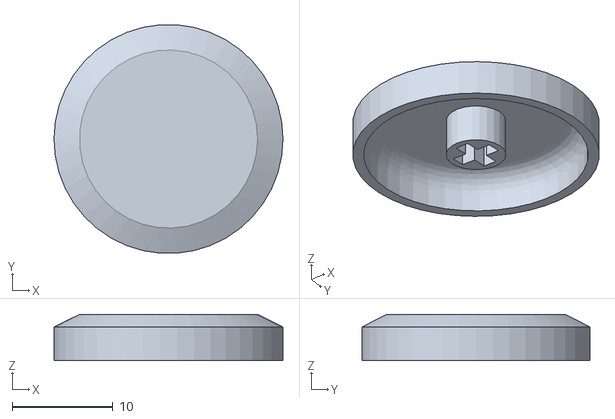
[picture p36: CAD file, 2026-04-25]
HitboardAir/02_3D_Files/More - 更多配件 /00_按键配件/配件_标准按键/00_硬朗按键（单个）/完美硬朗 23mm.stl
22.7 x 22.6 x 4.60

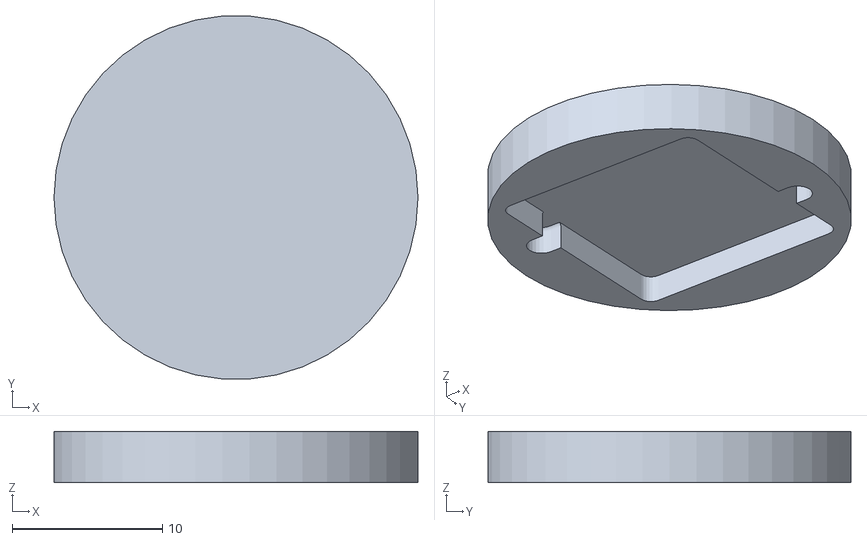
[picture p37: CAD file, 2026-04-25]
HitboardAir/02_3D_Files/More - 更多配件 /02_盖板配件/23mm 按键封帽_全封.stl
24.2 x 24.1 x 3.40

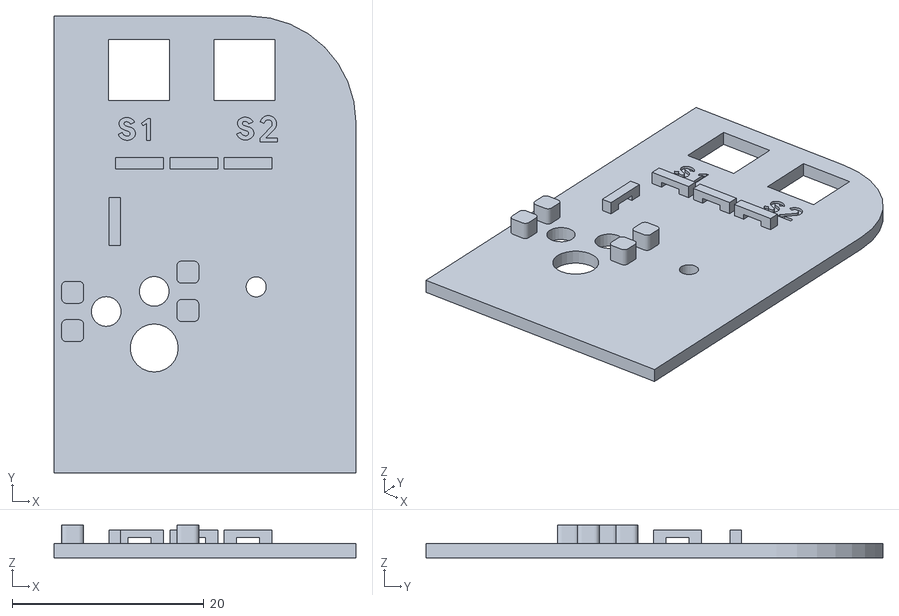
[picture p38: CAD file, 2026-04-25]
HitboardAir/02_3D_Files/More - 更多配件 /03_线路板配件/03_小板_适配微动按钮.stl
31.5 x 47.6 x 3.40

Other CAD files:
HitboardAir/02_3D_Files/Hitboard Air - 七星版（拳皇:绝区零:音游）/圆润线条/00_按键_圆润整套反打.stl
HitboardAir/02_3D_Files/Hitboard Air - 对称版（街霸特调）/硬朗线条/00_按键_硬朗整套反打.stl
HitboardAir/02_3D_Files/More - 更多配件 /00_按键配件/配件_标准按键/00_按键_圆润整套反打.stl
HitboardAir/02_3D_Files/More - 更多配件 /05_Dock（选配）/05_Dock_下半部分.stl
HitboardAir/02_3D_Files/180x180 打印机（A1mini ）/七星版（可加 w、shift 键）/圆润/01_盖板_右半.stl
HitboardAir/02_3D_Files/180x180 打印机（A1mini ）/七星版（可加 w、shift 键）/圆润/02_定位板_右半.stl
HitboardAir/02_3D_Files/180x180 打印机（A1mini ）/七星版（可加 w、shift 键）/圆润/02_定位板_左半.stl
HitboardAir/02_3D_Files/180x180 打印机（A1mini ）/七星版（可加 w、shift 键）/圆润/03_线路板_右半.stl
HitboardAir/02_3D_Files/180x180 打印机（A1mini ）/七星版（可加 w、shift 键）/圆润/03_线路板_左半.stl
HitboardAir/02_3D_Files/180x180 打印机（A1mini ）/七星版（可加 w、shift 键）/圆润/04_外壳_圆润_右半.stl
HitboardAir/02_3D_Files/180x180 打印机（A1mini ）/七星版（可加 w、shift 键）/圆润/04_外壳_圆润_左半.stl
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

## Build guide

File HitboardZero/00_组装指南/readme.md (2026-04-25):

### HITBOARD Air - 组装指南
1. 根据「Pico 正面」的引脚示意图，或根据「Pico 背面」印刷的文字，

将每个按键的轴座的 1 个引脚接到 Pico 的任意一个 GND 焊盘（圆孔）。

//可以用一根导线串联所有轴座的 GND

2. 讲轴座的另一个引脚，接到 Pico 对应功能的焊盘（圆孔）。

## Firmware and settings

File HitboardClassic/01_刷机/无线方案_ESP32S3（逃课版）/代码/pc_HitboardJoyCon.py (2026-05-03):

import serial
import serial.tools.list_ports
import threading
import time
import os
import logging
from flask import Flask, render_template_string, request, jsonify
from vgamepad import VX360Gamepad, XUSB_BUTTON
from pynput.keyboard import Controller, Key

# 关闭 Flask 请求日志
log = logging.getLogger('werkzeug')
log.setLevel(logging.ERROR)

# -------------------- 自动扫描串口 --------------------
def find_serial_port():
    for port in serial.tools.list_ports.comports():
        if "Bluetooth" in (port.description or "").lower():
            continue
        if "USB" in (port.description or "").lower() or "COM" in port.device or "tty.usbmodem" in port.device:
            return port.device
    return None

SERIAL_PORT = find_serial_port()
if SERIAL_PORT is None:
    print("错误：未找到可用串口，请检查接收器连接。")
    exit(1)

BAUDRATE = 460800
MAPPING_FILE = 'mapping.json'
KEYBOARD_MAPPING_FILE = 'keyboard_mapping.json'

# -------------------- 物理按键顺序 (Btn0~17) --------------------
PHYSICAL_KEYS = [
    "up", "down", "left", "right",     # 0-3
    "a", "b", "x", "y",                # 4-7
    "lb", "rb",                        # 8-9
    "lt", "rt",                        # 10-11
    "start", "select", "home", "capture", # 12-15
    "ls", "rs"                         # 16-17
]
BTN_COUNT = len(PHYSICAL_KEYS)

BTN_DISPLAY_NAMES = [f"Btn{i}: {PHYSICAL_KEYS[i]}" for i in range(BTN_COUNT)]

# -------------------- 内部键名 --------------------
INTERNAL_KEYS = [
    "None",
    "A", "B", "X", "Y",
    "DPAD_UP", "DPAD_DOWN", "DPAD_LEFT", "DPAD_RIGHT",
    "LB", "RB",
    "LT", "RT",
    "START", "BACK", "HOME",
    "LS", "RS"
]

XBOX_DISPLAY = [
    "None", "A", "B", "X", "Y",
    "↑", "↓", "←", "→",
    "LB", "RB", "LT", "RT",
    "菜单", "视图", "Xbox键", "LS", "RS"
]
SWITCH_DISPLAY = [
    "None", "B", "A", "Y", "X",
    "↑", "↓", "←", "→",
    "L", "R", "ZL", "ZR",
    "+", "-", "HOME", "左摇杆", "右摇杆"
]
PS5_DISPLAY = [
    "None", "✕", "◯", "□", "△",
    "↑", "↓", "←", "→",
    "L1", "R1", "L2", "R2",
    "选项", "创建", "PS", "左摇杆/L3", "右摇杆/R3"
]

PLATFORM_DISPLAY = {
    "Xbox": XBOX_DISPLAY,
    "Switch": SWITCH_DISPLAY,
    "PS5": PS5_DISPLAY
}

XBOX_OUTPUT_MAP = {
    "None": None,
    "A": XUSB_BUTTON.XUSB_GAMEPAD_A,
    "B": XUSB_BUTTON.XUSB_GAMEPAD_B,
    "X": XUSB_BUTTON.XUSB_GAMEPAD_X,
    "Y": XUSB_BUTTON.XUSB_GAMEPAD_Y,
    "DPAD_UP": XUSB_BUTTON.XUSB_GAMEPAD_DPAD_UP,
    "DPAD_DOWN": XUSB_BUTTON.XUSB_GAMEPAD_DPAD_DOWN,
    "DPAD_LEFT": XUSB_BUTTON.XUSB_GAMEPAD_DPAD_LEFT,
    "DPAD_RIGHT": XUSB_BUTTON.XUSB_GAMEPAD_DPAD_RIGHT,
    "LB": XUSB_BUTTON.XUSB_GAMEPAD_LEFT_SHOULDER,
    "RB": XUSB_BUTTON.XUSB_GAMEPAD_RIGHT_SHOULDER,
    "LT": "left_trigger",
    "RT": "right_trigger",
    "START": XUSB_BUTTON.XUSB_GAMEPAD_START,
    "BACK": XUSB_BUTTON.XUSB_GAMEPAD_BACK,
    "HOME": XUSB_BUTTON.XUSB_GAMEPAD_GUIDE,
    "LS": XUSB_BUTTON.XUSB_GAMEPAD_LEFT_THUMB,
    "RS": XUSB_BUTTON.XUSB_GAMEPAD_RIGHT_THUMB,
}

# -------------------- 默认映射 --------------------
DEFAULT_MAPPING = {
    "up":    ["DPAD_UP", "None"],
    "down":  ["DPAD_DOWN", "None"],
    "left":  ["DPAD_LEFT", "None"],
    "right": ["DPAD_RIGHT", "None"],
    "a":     ["A", "None"],
    "b":     ["B", "None"],
    "x":     ["X", "None"],
    "y":     ["Y", "None"],
    "lb":    ["LB", "None"],
    "rb":    ["RB", "None"],
    "lt":    ["LT", "None"],
    "rt":    ["RT", "None"],
    "start": ["START", "None"],
    "select":["BACK", "None"],
    "home":  ["HOME", "None"],
    "capture":["BACK", "None"],
    "ls":    ["LS", "None"],
    "rs":    ["RS", "None"],
}

# -------------------- 加载 / 保存按键映射 --------------------
def load_config():
    mapping = {}
    platform = "Xbox"
    if os.path.exists(MAPPING_FILE):
        try:
            with open(MAPPING_FILE, 'r') as f:
                data = json.load(f)
            platform = data.get("platform", "Xbox")
            saved = data.get("mappings", {})
            for key in PHYSICAL_KEYS:
                val = saved.get(key, DEFAULT_MAPPING.get(key, ["A", "None"]))
                if isinstance(val, str):
                    val = [val, "None"] if val != "None" else ["None", "None"]
                elif isinstance(val, list):
                    val = val[:2]
                    while len(val) < 2:
                        val.append("None")
                else:
                    val = ["None", "None"]
                val = [v if v in INTERNAL_KEYS else "None" for v in val]
                mapping[key] = val
        except Exception as e:
            print(f"加载配置失败：{e}")
    else:
        for key in PHYSICAL_KEYS:
            mapping[key] = DEFAULT_MAPPING.get(key, ["None", "None"])[:]
    return mapping, platform

def save_config(mapping, platform):
    data = {
        "mappings": mapping,
        "platform": platform
    }
    with open(MAPPING_FILE, 'w') as f:
        json.dump(data, f, indent=2)

current_mapping, current_platform = load_config()

# -------------------- 键盘映射配置 --------------------
def load_keyboard_mapping():
    if os.path.exists(KEYBOARD_MAPPING_FILE):
        try:
            with open(KEYBOARD_MAPPING_FILE, 'r') as f:
                return json.load(f)
        except:
            return []
    return []

def save_keyboard_mapping(mapping):
    with open(KEYBOARD_MAPPING_FILE, 'w') as f:
        json.dump(mapping, f, indent=2)

keyboard_mapping = load_keyboard_mapping()

# -------------------- 实时按钮状态 --------------------
current_button_states = [False] * BTN_COUNT
state_lock = threading.Lock()

# -------------------- 手柄输出 --------------------
def apply_action(gamepad, internal_key, press):
    if internal_key is None or internal_key == "None":
        return
    target = XBOX_OUTPUT_MAP.get(internal_key)
    if target is None:
        return
    if target == "left_trigger":
        gamepad.left_trigger_float(1.0 if press else 0.0)
    elif target == "right_trigger":
        gamepad.right_trigger_float(1.0 if press else 0.0)
    else:
        if isinstance(target, int):
            if press:
                gamepad.press_button(target)
            else:
                gamepad.release_button(target)

# -------------------- 键盘模拟（组合键同时按下并保持0.1秒）--------------------
keyboard_controller = Controller()

def parse_key_combination(keys_str):
    """解析组合键字符串，返回键对象列表"""
    if not keys_str:
        return []
    parts = keys_str.lower().split('+')
    result = []
    special = {
        'ctrl': Key.ctrl,
        'alt': Key.alt,
        'shift': Key.shift,
        'win': Key.cmd,
        'space': Key.space,
        'enter': Key.enter,
        'tab': Key.tab,
        'backspace': Key.backspace,
        'delete': Key.delete,
        'up': Key.up,
        'down': Key.down,
        'left': Key.left,
        'right': Key.right,
        'pageup': Key.page_up,
        'pagedown': Key.page_down,
        'home': Key.home,
        'end': Key.end,
    }
    for f in range(1, 13):
        special[f'f{f}'] = getattr(Key, f'f{f}')
    for p in parts:
        if p in special:
            result.append(special[p])
        elif len(p) == 1 and p.isalnum():
            result.append(p)
        else:
            # 未知键原样返回（可能报错）
            result.append(p)
    return result

def trigger_keyboard_combination(combo_str, hold_duration=0.1):
    """同时按下组合键中的所有键，保持 hold_duration 秒，然后同时释放"""
    if not combo_str:
        return
    keys = parse_key_combination(combo_str)
    if not keys:
        return
    # 同时按下
    for k in keys:
        keyboard_controller.press(k)
    time.sleep(hold_duration)
    # 同时释放
    for k in reversed(keys):
        keyboard_controller.release(k)

trigger_state = {}

def keyboard_trigger_loop():
    while True:
        with state_lock:
            states = current_button_states[:]
        for idx, mapping in enumerate(keyboard_mapping):
            btn1 = mapping.get("btn1")
            btn2 = mapping.get("btn2", -1)
            keys1 = mapping.get("keys1", "")
            keys2 = mapping.get("keys2", "")
            keys3 = mapping.get("keys3", "")
            cond = states[btn1] if btn1 is not None else False
            if btn2 != -1 and btn2 is not None:
                cond = cond and states[btn2]
            was = trigger_state.get(idx, False)
            if cond and not was:
                # 将三个按键组合成一个组合键字符串（非空部分用 '+' 连接）
                combo_parts = [k for k in (keys1, keys2, keys3) if k]
                if combo_parts:
                    combo_str = '+'.join(combo_parts)
                    trigger_keyboard_combination(combo_str, hold_duration=0.1)
                trigger_state[idx] = True
            elif not cond and was:
                trigger_state[idx] = False
        time.sleep(0.01)

keyboard_thread = threading.Thread(target=keyboard_trigger_loop, daemon=True)
keyboard_thread.start()

# -------------------- Flask Web 界面 --------------------
app = Flask(__name__)

HTML_TEMPLATE = """
<!DOCTYPE html>
<html>
<head>
    <title>Hitboard 设备配置</title>
    <meta charset="utf-8">
    <style>
        body { font-family: sans-serif; max-width: 800px; margin: 20px auto; padding: 0 20px; }
        .section { margin: 24px 0; border-top: 1px solid #ccc; padding-top: 16px; }
        .btn-grid { display: grid; grid-template-columns: repeat(9, 1fr); gap: 8px; }
        .btn-item { text-align: center; padding: 8px 4px; background: #e0e0e0; border-radius: 6px; font-size: 14px; }
        .btn-item.active { background: #1e2b3c; color: white; }
        .platform-nav { display: flex; gap: 0; margin: 12px 0 8px 0; }
        .platform-btn { padding: 8px 24px; border: 2px solid #1e2b3c; background: white; color: #1e2b3c; cursor: pointer; font-size: 14px; }
        .platform-btn:first-of-type { border-radius: 8px 0 0 8px; }
        .platform-btn:last-of-type { border-radius: 0 8px 8px 0; }
        .platform-btn.active { background: #1e2b3c; color: white; }
        .row { display: flex; align-items: center; margin: 5px 0; }
        .key { width: 60px; font-weight: bold; }
        select { margin-right: 8px; padding: 6px; width: 150px; }
        button { padding: 12px 30px; background: #1e2b3c; color: white; border: none; border-radius: 8px; font-size: 16px; font-weight: bold; cursor: pointer; }
        button:hover { opacity: 0.9; }
        h3 { margin-bottom: 5px; }
        .config-group { display: flex; flex-direction: column; gap: 12px; margin: 10px 0; }
        .config-item { display: flex; align-items: center; gap: 12px; background: #f5f5f5; padding: 8px 12px; border-radius: 8px; width: fit-content; }
        .config-item label { font-weight: bold; font-size: 0.9em; min-width: 200px; }
        .config-item select { width: 220px; margin: 0; }
        .keyboard-table { width: 100%; border-collapse: collapse; margin-top: 10px; }
        .keyboard-table th, .keyboard-table td { border: 1px solid #ddd; padding: 8px; text-align: left; }
        .keyboard-table th { background-color: #f2f2f2; }
        .delete-btn { background-color: #e74c3c; color: white; border: none; padding: 4px 8px; border-radius: 4px; cursor: pointer; }
        .add-row { margin-top: 10px; display: flex; flex-wrap: wrap; gap: 10px; align-items: center; }
        .kb-display { display: inline-block; min-width: 80px; cursor: pointer; background: #eee; padding: 4px 8px; border-radius: 4px; border: 1px solid #ccc; text-align: center; }
        .kb-display.recording { background: #ffeb3b; border-color: red; }
    </style>
</head>
<body>
    <h1>Hitboard 设置中心</h1>

    <!-- 设备信息配置区域 -->
    <div class="section">
        <h3>设备性能配置</h3>
        <div class="config-group">
            <div class="config-item"><label>回报率(Hz)</label><select id="polling_rate"><option value="250">250</option><option value="500">500</option><option value="800">800</option><option value="1000" selected>1000</option></select></div>
            <div class="config-item"><label>CPU频率(MHz)</label><select id="cpu_freq"><option value="80">80</option><option value="160">160</option><option value="240" selected>240</option></select></div>
            <div class="config-item"><label>发射功率</label><select id="tx_power"><option value="4">1 dBm (≈1-2米)</option><option value="12">3 dBm (≈3-5米)</option><option value="20" selected>5 dBm (≈5-8米)</option><option value="40">10 dBm (≈10-15米)</option><option value="84">21 dBm (≈20-30米)</option></select></div>
            <div class="config-item"><label>消抖(ms)</label><select id="debounce"><option value="0" selected>0</option><option value="3">3</option><option value="5">5</option><option value="10">10</option><option value="20">20</option></select></div>
            <div class="config-item"><label>电源选项（超时进入低功率模式）</label><select id="idle_timeout"><option value="5">5秒</option><option value="10">10秒</option><option value="30">30秒</option><option value="60" selected>60秒</option><option value="120">120秒</option></select></div>
        </div>
        <button onclick="saveDeviceConfig()">应用设备配置</button>
        <span id="deviceStatus" style="margin-left:10px;color:green"></span>
    </div>

    <!-- 按键查询面板 -->
    <div class="section">
        <h3>按键查询（按下对应的按键，高亮确认btn号）</h3>
        <div class="btn-grid" id="btnGrid">{% for i in range(btn_count) %}<div class="btn-item" id="btn{{i}}">Btn{{i}}</div>{% endfor %}</div>
    </div>

    <!-- 手柄按键映射 -->
    <div class="section">
        <h3>手柄按键映射（每个按键最多两个输出）</h3>
        <div class="platform-nav">{% for p in platforms %}<div class="platform-btn {% if p == platform %}active{% endif %}" data-platform="{{p}}" onclick="switchPlatform('{{p}}')">{{p}}</div>{% endfor %}</div>
        <p style="color: gray; font-size: 12px; margin-top: -5px;">切换平台仅改变按键显示名称，不影响实际输出</p>
        <div id="mappingArea" style="margin-top: 12px;">{% for i in range(btn_count) %}<div class="row"><span class="key">Btn{{i}}</span><select id="map_{{i}}_1">{% for opt in display_options %}<option value="{{ internal_keys[loop.index0] }}" {% if current_mapping[key_list[i]][0] == internal_keys[loop.index0] %}selected{% endif %}>{{ opt }}</option>{% endfor %}</select><select id="map_{{i}}_2">{% for opt in display_options %}<option value="{{ internal_keys[loop.index0] }}" {% if current_mapping[key_list[i]][1] == internal_keys[loop.index0] %}selected{% endif %}>{{ opt }}</option>{% endfor %}</select></div>{% endfor %}</div>
        <button onclick="saveSettings()">保存按键映射</button>
        <p id="status"></p>
    </div>

    <!-- 键盘按键触发配置 -->
    <div class="section">
        <h3>键盘按键触发</h3>
        <p style="color: gray; font-size: 12px;">当两个手柄按键同时按下时，触发下方三个键盘按键的组合（同时按下并保持0.1秒）。点击输入框录制单个按键，修改下拉框自动保存。</p>
        <table class="keyboard-table" id="keyboardTable">
            <thead><tr><th>手柄按键1</th><th>手柄按键2</th><th>键盘按键1</th><th>键盘按键2</th><th>键盘按键3</th><th>操作</th></thead>
            <tbody id="keyboardTbody"></tbody>
        </table>
        <div class="add-row">
            <select id="new_btn1">{% for i in range(btn_count) %}<option value="{{ i }}">{{ btn_display_names[i] }}</option>{% endfor %}</select>
            <select id="new_btn2"><option value="-1">无</option>{% for i in range(btn_count) %}<option value="{{ i }}">{{ btn_display_names[i] }}</option>{% endfor %}</select>
            <span class="kb-display" id="new_keys1_display" data-keyidx="0">未设置</span>
            <span class="kb-display" id="new_keys2_display" data-keyidx="1">未设置</span>
            <span class="kb-display" id="new_keys3_display" data-keyidx="2">未设置</span>
            <button onclick="addKeyboardMapping()">添加配置</button>
        </div>
    </div>

    <script>
        const btnCount = {{ btn_count }};
        let keyboardMapping = {{ keyboard_mapping | tojson }};
        let recordingActive = false;
        let currentRecordingContext = null;

        const keyNameMap = {
            'Control': 'ctrl', 'Alt': 'alt', 'Shift': 'shift', 'Meta': 'win',
            ' ': 'space', 'Space': 'space', 'Enter': 'enter', 'Tab': 'tab',
            'Backspace': 'backspace', 'Delete': 'delete', 'ArrowUp': 'up',
            'ArrowDown': 'down', 'ArrowLeft': 'left', 'ArrowRight': 'right',
            'PageUp': 'pageup', 'PageDown': 'pagedown', 'Home': 'home', 'End': 'end',
            'F1':'f1','F2':'f2','F3':'f3','F4':'f4','F5':'f5','F6':'f6',
            'F7':'f7','F8':'f8','F9':'f9','F10':'f10','F11':'f11','F12':'f12',
        };
        function normalizeKey(e) {
            let key = e.key;
            if (keyNameMap[key]) return keyNameMap[key];
            if (key.length === 1) return key.toLowerCase();
            return key.toLowerCase();
        }

        function startRecording(target, context) {
            if (recordingActive) return;
            recordingActive = true;
            currentRecordingContext = context;
            target.classList.add('recording');
            target.innerText = '请按下按键...';
            window.addEventListener('keydown', onRecordingKeyDown);
            window.addEventListener('keyup', onRecordingKeyUp);
        }

        function stopRecording(recordKey) {
            if (!recordingActive) return;
            window.removeEventListener('keydown', onRecordingKeyDown);
            window.removeEventListener('keyup', onRecordingKeyUp);
            const target = currentRecordingContext.target;
            target.classList.remove('recording');
            if (recordKey !== null) {
                target.innerText = recordKey;
                const { type, rowIndex, keyIdx } = currentRecordingContext;
                if (type === 'edit') {
                    const mapping = keyboardMapping[rowIndex];
                    if (mapping) {
                        if (keyIdx === 0) mapping.keys1 = recordKey;
                        else if (keyIdx === 1) mapping.keys2 = recordKey;
                        else if (keyIdx === 2) mapping.keys3 = recordKey;
                        saveKeyboardMappingToServer(keyboardMapping);
                        renderKeyboardTable();
                    }
                } else if (type === 'add') {
                    const displaySpan = target;
                    displaySpan.innerText = recordKey;
                    displaySpan.setAttribute('data-value', recordKey);
                }
            }
            recordingActive = false;
            currentRecordingContext = null;
        }

        function onRecordingKeyDown(e) {
            if (!recordingActive) return;
            e.preventDefault();
            e.stopPropagation();
            const key = normalizeKey(e);
            stopRecording(key);
        }
        function onRecordingKeyUp(e) {}

        async function saveKeyboardMappingToServer(newMapping) {
            // 只更新后端，不重新拉取（避免递归）
            await fetch('/api/keyboard_config', {
                method: 'POST',
                headers: {'Content-Type': 'application/json'},
                body: JSON.stringify({ action: 'sync', mapping: newMapping })
            });
        }

        async function handleMappingChange(rowIndex, field, value) {
            const mapping = keyboardMapping[rowIndex];
            if (!mapping) return;
            mapping[field] = value;
            await saveKeyboardMappingToServer(keyboardMapping);
        }
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

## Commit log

2026-04-04 Update 00_设计你的Hitboard Airv1.0.9.html
2026-04-22 Hitboard Classic
    [24mm 圆键（MX轴 x16 组）.stl, 24mm 圆键（凯华矮轴轴 x16 组）.stl, M2 螺丝垫片.stl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]
2026-04-22 盖板、外壳卡扣优化。
    卡扣改为隐藏式。
    [外壳本体.stl, 盖板-Mixboard（混合）.stl, 盖板-Mixboard（纯血）.stl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]
2026-04-22 Update 00_设计你的 Hitboard Classic～.html
2026-04-22 解放盖板左侧螺丝，Creator 更新
    [盖板-Mixboard（混合）.stl, 盖板-Mixboard（纯血）.stl, 盖板-街机（混合）.stl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]
2026-04-22 增加摇杆挡片
    [摇杆挡片.stl]
2026-04-23 外壳底部封帽增加一字螺丝孔。
    [外壳组件.stl, 封帽-底洞.stl]
2026-04-23 解封盖板右侧螺丝
    [盖板-Mixboard（混合）.stl, 盖板-Mixboard（纯血）.stl, 盖板-街机（混合）.stl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]
2026-04-23 增加 A1mini 套件，优化外壳右上角卡扣
    [外壳右半.stl, 外壳左半.stl, 外壳本体.stl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]
2026-04-23 回复左侧卡扣，以支持镜像。
    [外壳右半.stl, 外壳左半.stl, 外壳本体.stl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]
2026-04-24 轴体切换
    [功能键（三和轴 x3 组）.stl, 功能键（宝联轴 x3 组）.stl, 轴座-功能键-三和轴.stl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]
2026-04-24 Create Hitboard Classic 亚克力.dwg
    [Hitboard Classic 亚克力.dwg]
2026-04-24 增加壁纸支撑板
    [Hitboard Classic 亚克力.dwg, 街机:Hitbox 壁纸支撑板-右.stl, 街机:Hitbox 壁纸支撑板-左.stl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]
2026-04-24 Update Hitboard Classic 亚克力.dwg
    [Hitboard Classic 亚克力.dwg]
2026-04-25 网页设计工具更新
2026-04-25 新增三和摇杆滑轨
    [轨道-摇杆台（三和JLX2）.stl, 轨道-摇杆台（宝联:拳霸）.stl]
2026-04-25 图片更新
2026-04-27 Zero 轴座板优化
    功能键区域改为可剪断结构，方便在缠线导电、电路板导电之间切换。
    [24mm 圆键（MX轴 x16 组）.stl, 24mm 圆键（凯华矮轴轴 x16 组）.stl, Hitboard Zero v0.18.dwg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]
2026-04-27 Mixboard 键帽说明
    [Hitboard Zero v0.19.dwg]
2026-04-27 Classic 新增「大杯」
    [大杯_外壳_右.stl, 大杯_外壳_左.stl, 大杯_盖板_右.stl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]
2026-04-27 支持 22mm 圆键帽、支持全尺寸键盘键帽
    [Hitboard Classic 亚克力 0.2 兼容 22mm 键帽.dwg, Hitboard Classic 亚克力.dwg, 盖板-Mixboard（混合）.stl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]
2026-04-27 更新按键
    [24mm 圆键（MX轴 x16 组）.stl, 24mm 圆键（凯华矮轴轴 x16 组）.stl, 功能键-拨杆开关底座.stl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]
2026-04-27 文件调整
    [外壳锁扣（打印两个）.stl, 超大杯_外壳_锁壳（打印两个）.stl]
2026-04-27 大杯盖板
    [大杯_盖板_右.stl, 大杯_盖板_左.stl, 盖板-街机（混合）右.stl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]
2026-04-27 新增按键薄轴座
    [薄轴座-24mm 圆形按键-MX 轴.stl, 薄轴座-24mm 圆形按键-矮轴.stl, 轴座-24mm 圆形按键-MX 轴.stl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]
2026-04-27 超薄轴座
    [超薄轴座-圆形按键-MX 轴.stl, 超薄轴座-圆形按键-矮轴.stl, 轴座-圆形按键-MX 轴.stl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]
2026-04-27 大杯增加圆形功能键
    [盖板-街机（混合）右.stl, 盖板-街机（混合）左.stl, 盖板-街机（纯血）右.stl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]
2026-04-27 更新封帽
    [封帽-24mm 圆.stl, 封帽-Mix 宽.stl, 封帽-Mixboard 宽.stl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]
2026-04-27 目录调整。
    [Hitboard Classic 亚克力 0.2 兼容 22mm 键帽.dwg, Hitboard Classic 亚克力.dwg, M2 螺丝垫片.stl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]
2026-04-28 盖板去掉 LOGO
    [盖板-街机（混合）.stl, 盖板-街机（混合）右.stl, 盖板-街机（混合）左.stl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]
2026-04-28 盖板更新
    [外壳组件.stl, 封帽-Shift.stl, 封帽-方.stl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]
2026-04-28 新增壁纸支撑板
    [摇杆防尘片.stl, 支撑板-标准版-Mixbox.stl, 支撑板-标准版-街机:Hitbox.stl]
2026-04-28 亚克力文件更新
    [Hitboard Classic 亚克力 0.3.dwg, Hitboard Classic 亚克力 0.4.dwg]
2026-04-28 Creator 更新
2026-04-28 摇杆轨道改为零公差设计。
    [外壳组件.stl, 轨道-摇杆台（三和JLX2）.stl, 轨道-摇杆台（宝联:拳霸）.stl]
2026-04-28 大杯优化
    [外壳锁扣（打印两个）.stl, 大杯_外壳_右.stl, 大杯_外壳_左.stl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]
2026-04-28 更新大杯
    [大杯外壳右.stl, 大杯外壳左.stl, 大杯盖板右.stl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]
2026-04-29 大杯外壳更新
    [外壳右.stl, 外壳左.stl, 大杯外壳右.stl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]
2026-04-29 大杯更新
    [外壳右.stl, 外壳锁扣（打印两个）.stl, 盖板混合-右.stl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]
2026-04-29 更新大杯，更新尺寸说明
    [外壳右.stl, 外壳左.stl, 外壳锁扣（打印两个）.stl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]
2026-04-29 不推荐大杯
    [外壳右.stl, 外壳左.stl, 外壳锁扣（打印两个）.stl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]
2026-04-29 大杯说明
2026-04-30 优化
    优化外壳与盖板的卡扣系统。
    优化按键开孔。
    [外壳右半.stl, 外壳左半.stl, 外壳本体.stl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]
2026-04-30 目录调整
    [功能键（宝联轴 x3 组）.stl, 轴座-功能键-宝联轴.stl, 键帽-22mm 圆形按键-硬朗.stl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]
2026-04-30 盖板亚克力更新
    [Hitboard Classic 亚克力 0.4.dwg, Hitboard Classic 亚克力 0.5.dwg, 封帽圆.stl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]
2026-05-01 Air Dock 螺丝孔优化、线条优化
    [05_Dock_上半部分.stl, 05_Dock_下半部分.stl]
2026-05-02 大杯维护中
    [外壳右.stl, 外壳左.stl, 外壳锁扣（打印两个）.stl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]
2026-05-02 新增无线方案
2026-05-02 无线方案
2026-05-02 无线方案增加功率设置功能
2026-05-02 无线方案，新增降频接收器
2026-05-03 无线方案，新增键盘按键触发
    [外壳-右半.stl, 外壳-左半.stl, 外壳组件（含锁扣）.stl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]
2026-05-03 按键系统更新
    [超薄轴座-圆形按键-MX 轴.stl, 超薄轴座-圆形按键-矮轴.stl, 轴座-Mixboard 宽按键-MX轴(打印时开启支撑).stl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]
2026-05-03 优化功能键区域磁铁开孔
    [盖板-左半(纯摇杆).stl, 盖板-左半（带 Hitbox 方向键开孔）.stl]
2026-05-03 标准版 A1mini 增加卡扣
    [拨杆开关底座-挡片.stl, 拨杆开关底座.stl, 盖板-Mixbox（混合）右.stl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]
2026-05-03 外壳增加可激活电池仓
    [外壳-右半.stl, 外壳右半.stl, 外壳本体.stl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]
2026-05-03 外壳电池仓结构优化
    [M2 螺丝垫片.stl, 外壳-右半.stl, 外壳-左半.stl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]
2026-05-03 文件整理
    [.stl, 外壳组件.stl, 摇杆色彩环.stl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]
2026-05-03 新增 22mm 键帽
    [键帽-22mm 圆形按键-圆润.stl]
2026-05-03 外壳-可激活电池盖优化
    [外壳右半.stl, 外壳左半.stl, 外壳本体.stl]
2026-05-03 大杯电池盖优化
    [外壳 290x180.stl, 外壳-右半.stl]
2026-05-04 新增大杯亚克力盖板 CAD
    [Hitboard Classic 亚克力 0.3.dwg, Hitboard Classic 亚克力 0.5.dwg, 亚克力盖板-Large 大杯.dwg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]
2026-05-04 增加蓝牙代码
2026-05-04 盖板恢复 Logo
    [盖板-街机（混合）.stl, 盖板-街机（混合）右.stl, 盖板-街机（混合）左.stl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]
2026-05-04 大杯 LOGO
    [外壳 290x180.stl, 盖板-290x180.stl.stl, 盖板-右半.stl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]
2026-05-05 优化外壳左右螺丝仓阻尼
    [外壳-右半.stl, 外壳-左半.stl, 外壳右半.stl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]
2026-05-06 新增：小摇距圆方限位环
    [外壳-290x180.stl, 摇杆限位环-圆方(小摇距版).stl, 摇杆限位环-圆方.stl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]
2026-05-08 去掉不好用的小摇距
    [外壳本体.3mf, 摇杆限位环-圆方(小摇距版).stl]
2026-05-09 新增支持 23mm 键帽的套件
    [MX 轴.stl, 外壳本体.3mf, 盖板（大杯右侧）（左侧不需要改）.stl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]
2026-05-10 23mm键帽亚克力
    [亚克力盖板-标准版中杯 23mm 键帽.dwg, 键帽-22mm 圆形按键-圆润.stl, 键帽-22mm 圆形按键-硬朗.3mf]
2026-05-12 默认按键为圆润
    [轴座-Mixboard 宽按键-MX轴(打印时开启支撑).stl, 轴座-Mixboard 宽按键-矮轴(打印时开启支撑).stl, 轴座-功能键-MX 轴.stl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]
